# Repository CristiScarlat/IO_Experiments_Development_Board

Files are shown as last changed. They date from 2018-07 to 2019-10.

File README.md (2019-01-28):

IO_Experiments is a developer kit on a single board. The developer can connect any uC board including Arduino , Nucleo , RasperryPi to any of the devices on this board.

The board contains:
1. LCD 16x2 alphanumeric;
2. 8xleds driven by ULN2803;
3. 8xpush buttons;
4. 8xPots;
5. 7 segment display driven with cd4511;
6. 1x led matrix display driven by a MAX7219
7. 1xConnection made for Aurel 433MHz transiver;
8. 1xRTC PCF8563 I2C;
9. 3xIO Expanders MCP23017 I2C;
10. 1xEEPROM AT24CP I2C;
11. 1xFLASH MEM 25VF512A SPI ;
12. 1xDC Motor Drive L298;
13. 8xToggle Switches;
14. 1xRotary Encoder;
15. 1xJoystick;
16. 1xPiezzo Buzzer;
17. 1xLight Sensor;
18. 1xTemperature Sensor TMP36;
19 1xIR sensor 38KHz TSOP3483;
10. 1xDAC 12bit MCP4921 SPI ;
11. 1xADC 12bit MCP3201 SPI;
12. 8xRelays driven by ULN2803;

The boards has a 5V 3A power regulator and 3.3V 800mA power regulator.

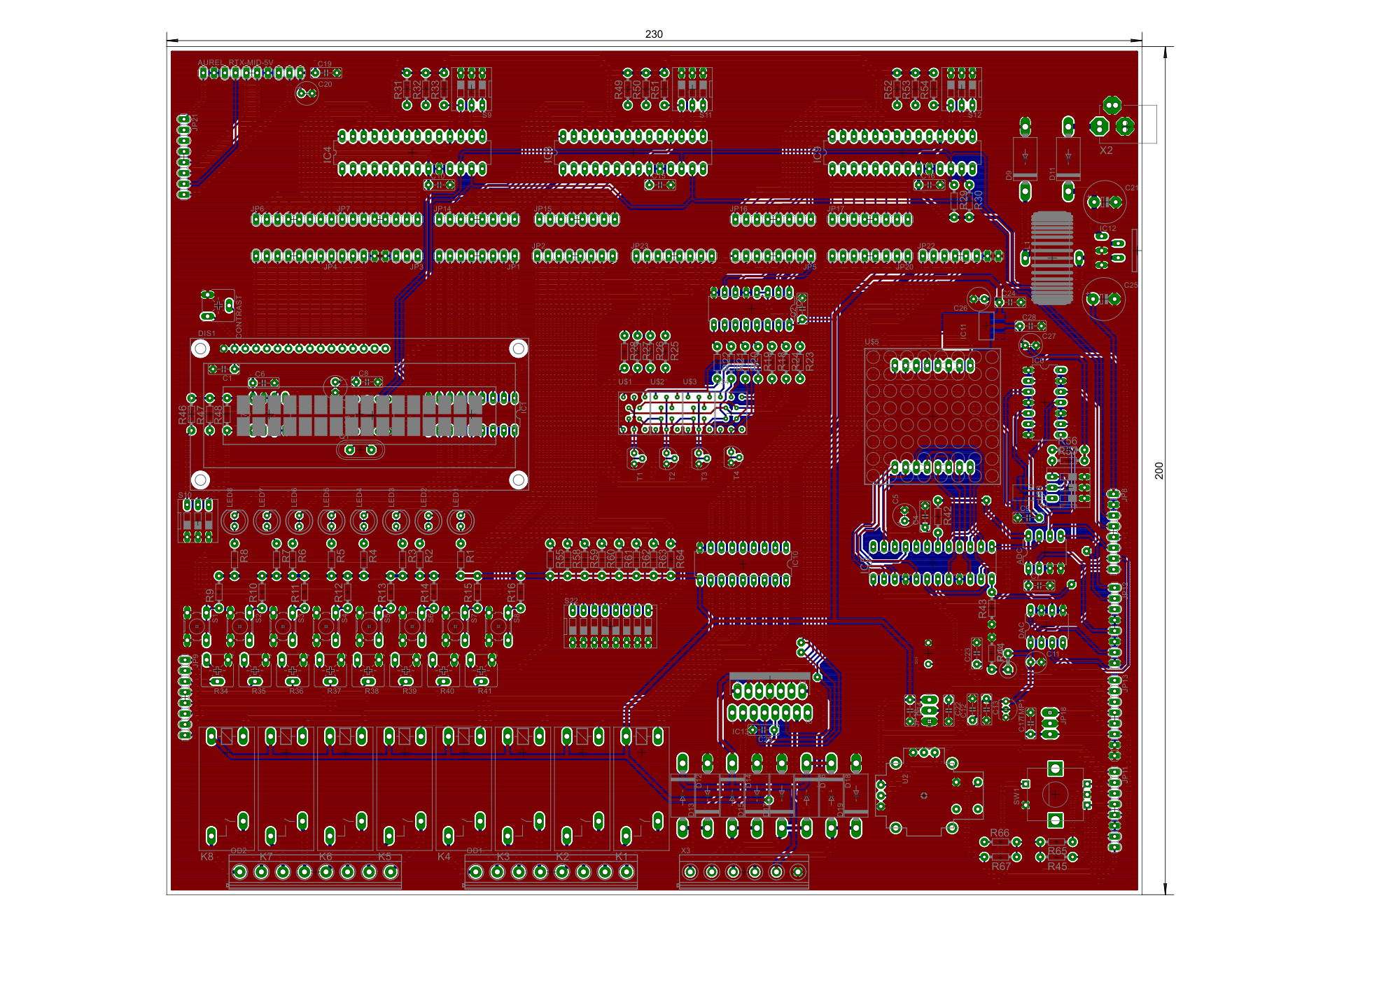
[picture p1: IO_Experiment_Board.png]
IO_EXPERIMENT_BOARD


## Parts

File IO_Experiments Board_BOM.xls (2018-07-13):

Qty | Value | Device | Package | Parts | DENUMIRE TME | PRET TME
1 |  | 0550_PKM13EPYH4002-B0 | BUZZER-12MM-NS-P5MM | SG1 | LD-BZEN-1201? | 1.2043RON/3buc
1 |  | LM2596TV | TO220-51 | IC12 | LM2596T-5.0? | 13.5RON/buc
1 |  | M03LONGPADS | 1X03_LONGPADS | IR | TSOP34838 | 2.08RON/buc
1 |  | R-US_0411/3V | 0411V | R17 | GM5516? | 0.2318RON/10buc
8 | 10-XX | 10-XX | B3F-10XX | B1, B2, B3, B4, B5, B6, B7, B8 | TACT-67N-F? | 0.1713RON/10buc
19 | 100nF | C5/2.5 | C5B2.5 | C1, C2, C4, C6, C7, C8, C9, C10, C12, C13, C14, C15, C16, C17, C19, C23, C29,C24, C28 | CC-100N? | 0.04901RON/100buc
3 | 100uF | CPOL-EUE2.5-6 | E2,5-6 | C20, C26, C27 | KM100/16? | 0.12RON/25buc
38 | 10k | RRS1/8 | RS1/8 | R9, R10, R11, R12, R13, R14, R15, R16, R45, R55, R58, R59, R60, R61, R62, R63, R64, R65, R66, R67,R29, R30, R31, R32, R33, R43, R44, R46, R47, R48, R49, R50, R51, R52, R53, R54, R56, R57 | CF1/4W-10K? | 0.02662RON/100buc
2 | 1N5822 | 1N5822 | DO201-15 | D9, D11 | 1N5822? | 0.3932RON/10buc
3 | 1uF | CPOL-EUE2.5-6 | E2,5-6 | C3, C5,C11 | CM-1U | 0.21524RON/10buc
9 | 20k | TRIM_EU-CA6V | CA6V | CONTRAST, R34, R35, R36, R37, R38, R39, R40, R41 | CA6V-10K? | 0.5689RON/5buc
15 | 220 | RRS1/8 | RS1/8 | R1, R2, R3, R4, R5, R6, R7, R8, R18, R19, R20, R21, R22, R23, R24 | CF1/4WS-220R | 0.0291RON/100buc
1 | 25VF512A-33SAE | 25VF512A-33SAE | SOIC-8 | U$8 | 25VF512A-33SAE? | 2.4427RON/3buc
1 | 27k | REZISTORSRS1/8 | RS1/8 | R42 | CF1/4WS-27K? | 0.02905RON/100buc
1 | 32.768 kHz | CRYSTAL_THT | QS | Q1 | 32.768K-TC38 | 0.6109RON/5buc
5 | 3DIP_SW | DS03 | DS-03 | S9, S10, S11, S12, S13 | DS-03 | 2.5057RON/2buc
4 | 4.7k | RRS1/8 | RS1/8 | R25, R26, R27, R28 | MF0207FTE-4K7? | 0.07144RON/100buc
1 | 4511N | 4511N | DIL16 | IC2 | CD4511BE? | 1.1205RON/3buc
2 | 470uF | CPOL-EUE5-10.5 | E5-10,5 | C21, C25 | CE-470/16PHT? | 0.16463RON/25buc
1 | 74125N | 74125N | DIL14 | IC6 | SN74AHC125N? | 0.7279RON/5buc
1 | 8DIP_SW | DS08 | DS-08 | S22 | DS-08? | 4.4522RON/buc
1 | AT24CP | AT24CP | DIL08 | IC7 | AT24C02C-PUM? | 1.45RON/3buc
4 | BC547 | BC547 | TO92 | T1, T2, T3, T4 | BC547A? | 0.08948RON/25buc
1 | EC12E_SW | EC12E_SW ENCODER | ALPS_EC12E_SW | SW1 | ED16112O? | 9.31RON/buc
1 | FH254-106DF08500V | FH254-106DF08500V_STD | 1X06 | EXT_SENS | ZL262-6SG? | 0.24RON/10buc
20 | FH254-108DF08500V | FH254-108DF08500V | 1X08 | 7SEG, BUTTONS, COMMUNICATION, DIP_SW, ENCJOY, JP6, JP7, JP12, JP14, JP15, JP16, JP17, JP20, JP21, JP22, LCDH, LCDL, LEDS, POTS, SENSORS | ZL262-8SG? | 0.28426RON/10buc
1 | FH254-110DF08500V | FH254-110DF08500V | 1X10 | AUREL_RTX-MID-5V | ZL262-10SG? | 0.26649RON/10buc
1 | LFD039AUE-102A? | LFD039AUE-102A? | LFD039AUE-102A? | 1 | LFD039AUE-102A? | 3.04RON/buc
8 | G2RA | G2RA | G2RA | K1, K2, K3, K4, K5, K6, K7, K8 | G2R-1A4-5DC? | 5.55RON/buc
8 | GREEN_5mm | L-7113GT | LED5MM | LED1, LED2, LED3, LED4, LED5, LED6, LED7, LED8 | OSNR5134B? | 0.1283RON/20buc
1 | JOYSTICK | JOYSTICKPTH | JOYSTICK | U2 | http://www.robofun.ro/joystick?search=joystick
1 | L298 | L298 | MULTIWATT-15 | IC13 | L298N? | 10.95RON/nuc
1 | LMD12088AUE-101A | LMD12088AUE-101A | NFM-12881BG-11 | U$5 | LMD12088AUE-101A | 6.69RON/buc
1 | MAX7219CNG | MAX7219CNG | DIL24-3 | IC5 | MAX7219CNG+ | 26.92RON/buc
8 | MBRA140 | 1N5400 | DO201-15 | D12, D13, D14, D15, D16, D17, D18, D19 | 1N5402? | 0.28922RON/10buc
3 | MCP23017SP | MCP23017SP | DIL28-3 | IC4, IC8, IC9 | MCP23017-E/SP? | 5.12RON/buc
1 | MCP3201-CI/P | MCP3201-CI/P | DIL08 | ADC | MCP3201-CI/P? | 10.74RON/buc
1 | MCP4921 | MCP4921 | DIL08 | DAC | MCP4921-E/P? | 8.10RON/buc
1 | MKDSN1,5/6-5,08 | MKDSN1,5/6-5,08 | MKDSN1,5/6-5,08 | X3
2 | MKDSN1,5/8-5,08 | MKDSN1,5/8-5,08 | MKDSN1,5/8-5,08 | OD1, OD2
1 | NX1117CE33Z | NX1117CE33Z,115 | SOT223 | IC11 | LD1117AS33? | 0.7942RON/3buc
1 | PCF8563P | PCF8563P | DIL08 | IC3
1 | POWERSUPPLY_DC21MMX | POWERSUPPLY_DC21MMX | POWERSUPPLY_DC-21MM | X2 | PC-GK1.3 | 0.5784RON/5buc
1 | SFT1030 | SFT1030 | SFT1030 | L1 | DTPU033A1? | 3.10RON/buc
1 | TMP36 | TMP36 | BC-TO92 | TMP1 | TMP36GT9Z? | 4.30RON/buc
1 | LCD_16X2 | LCD_16X2 | LCD_16X2 | DIS1 | RC1602B? | 23.22RON.buc
2 | ULN2803 | ULN2803A | DIL18 | IC1, IC10 | ULN2803A? | 2.1743RON/buc

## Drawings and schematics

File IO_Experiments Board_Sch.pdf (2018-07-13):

# LED_MATRIX

433MHz UART RX_TX | SURSA TENSIUNE

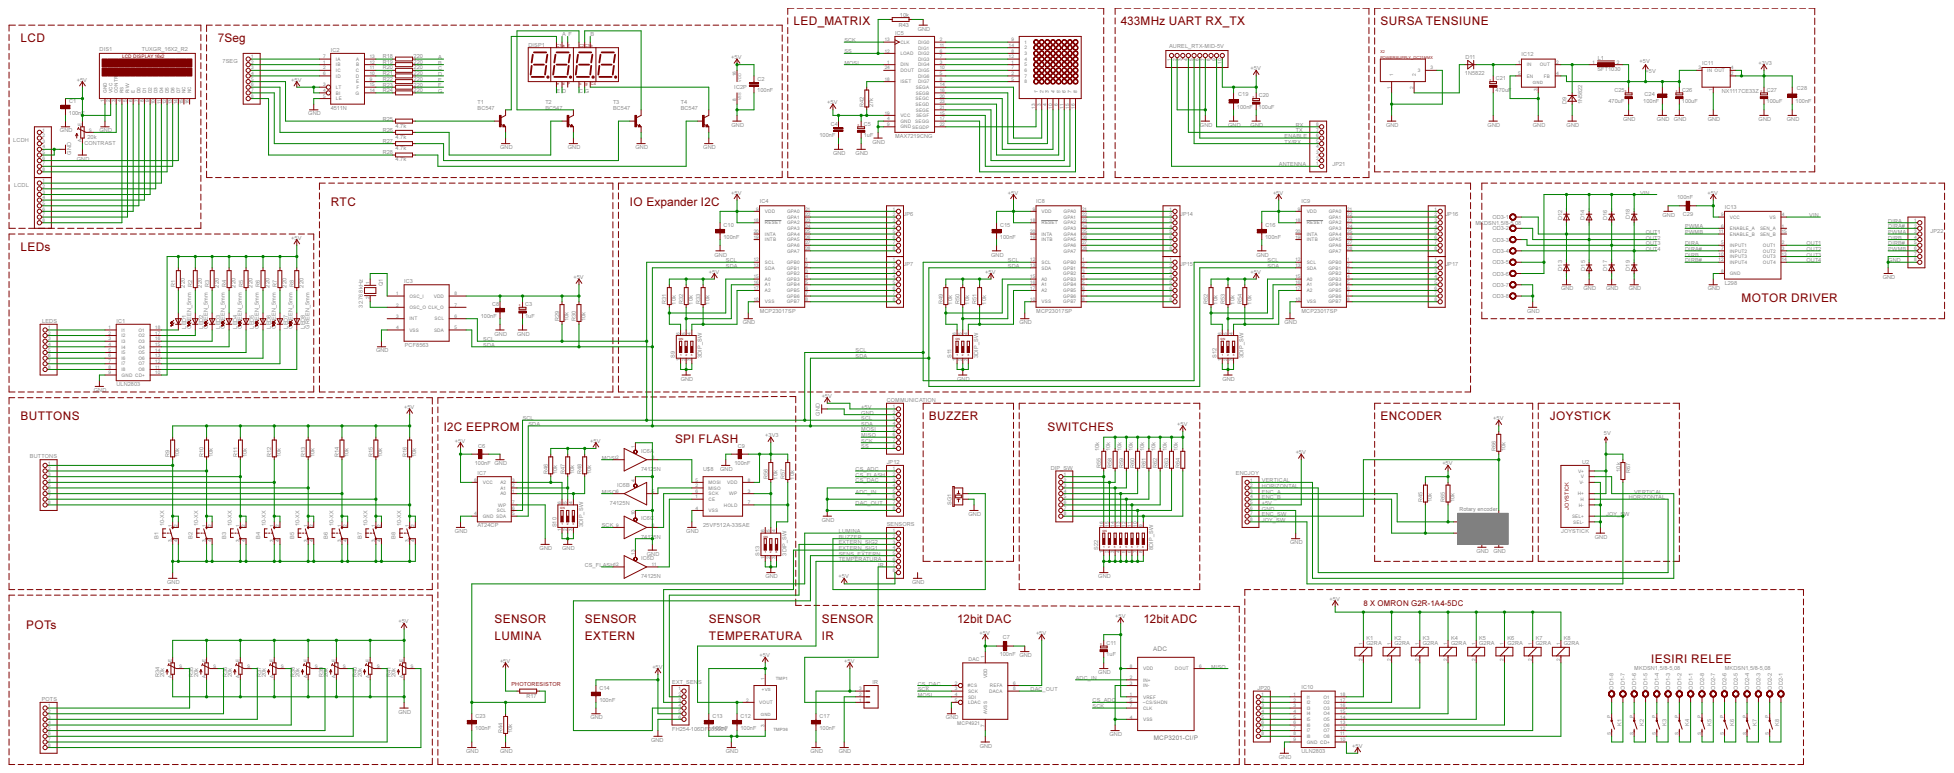
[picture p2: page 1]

SpiceOrder 1 SpiceOrder 2

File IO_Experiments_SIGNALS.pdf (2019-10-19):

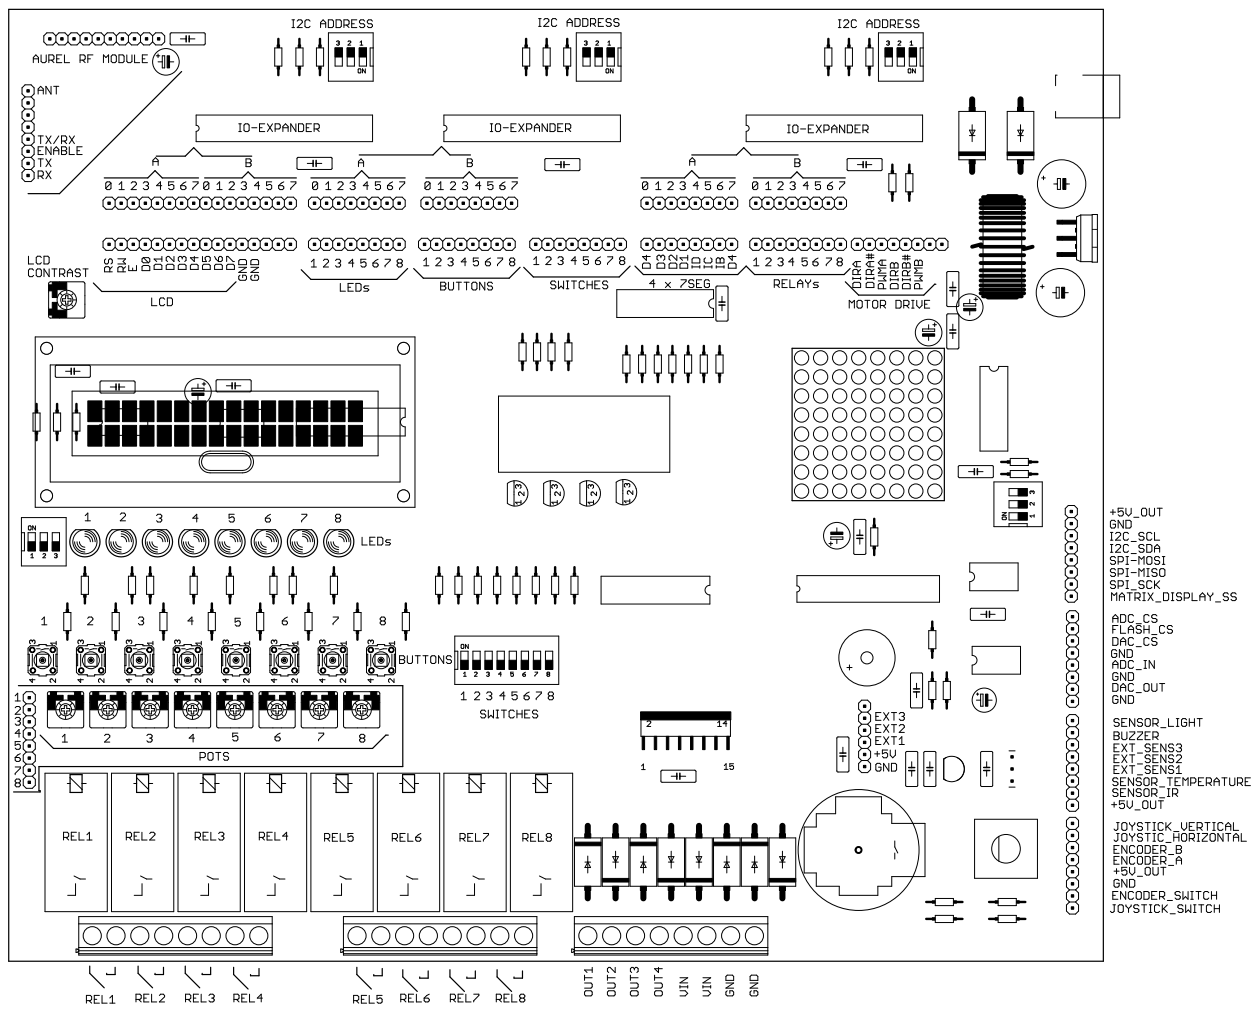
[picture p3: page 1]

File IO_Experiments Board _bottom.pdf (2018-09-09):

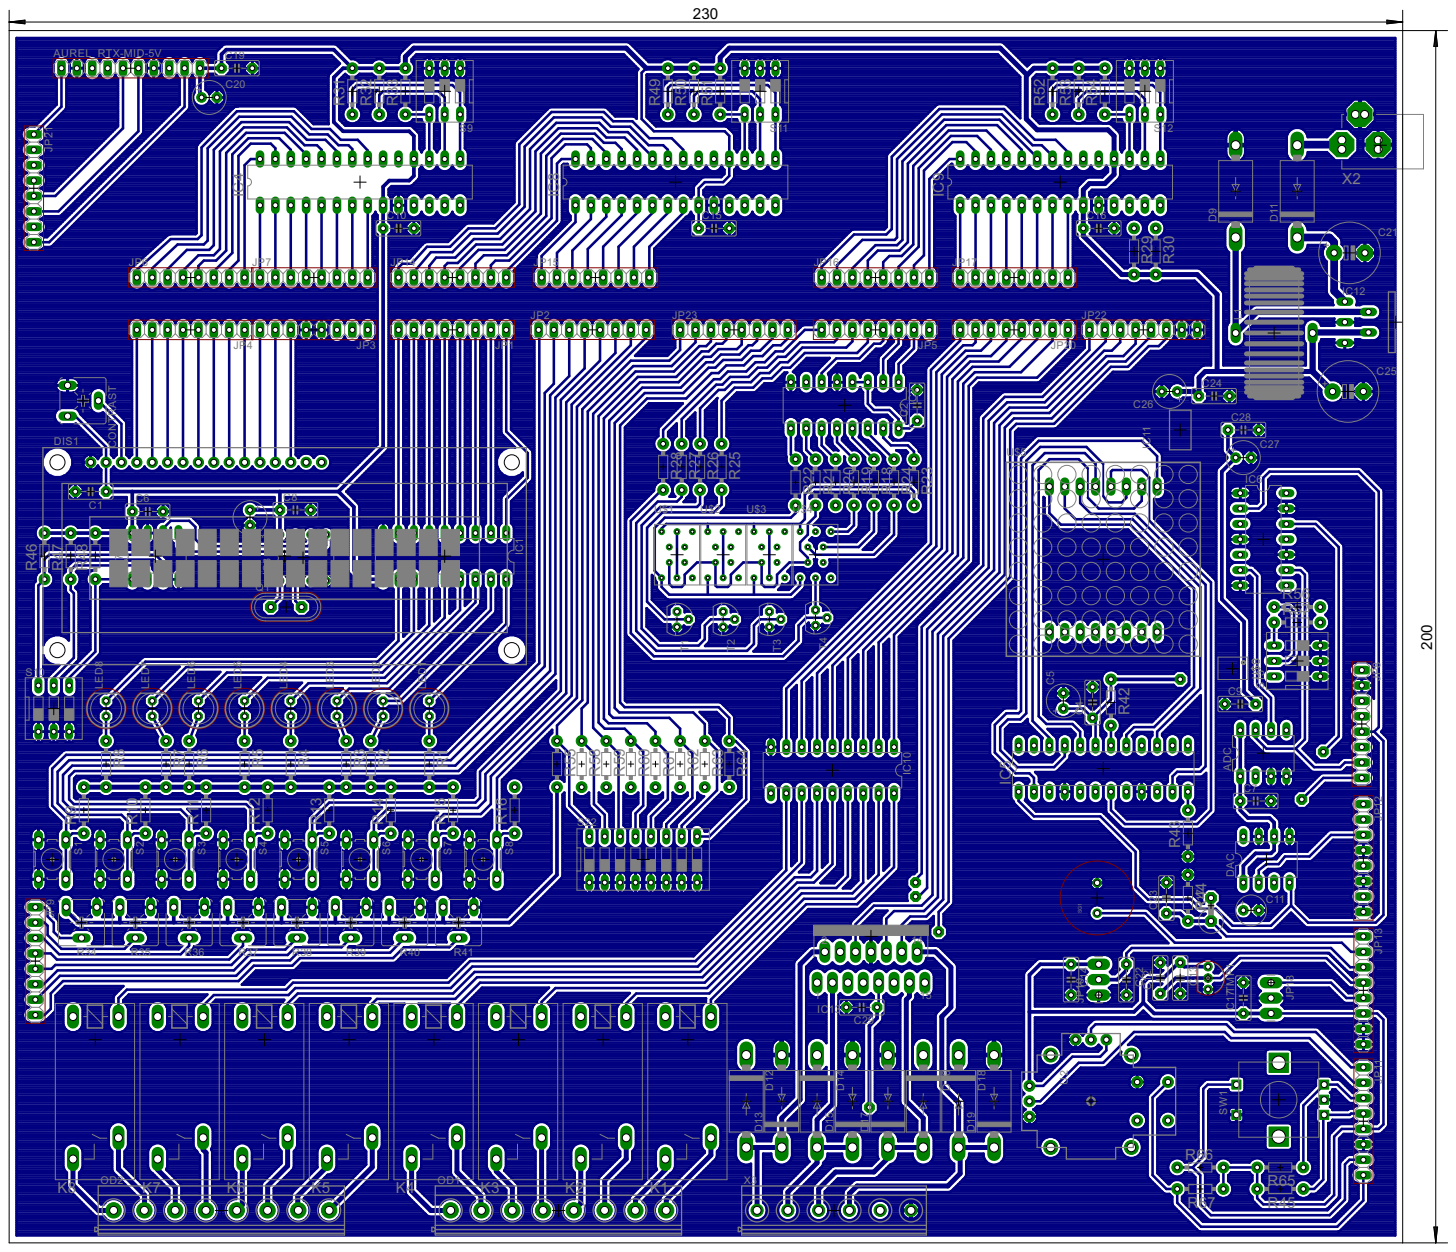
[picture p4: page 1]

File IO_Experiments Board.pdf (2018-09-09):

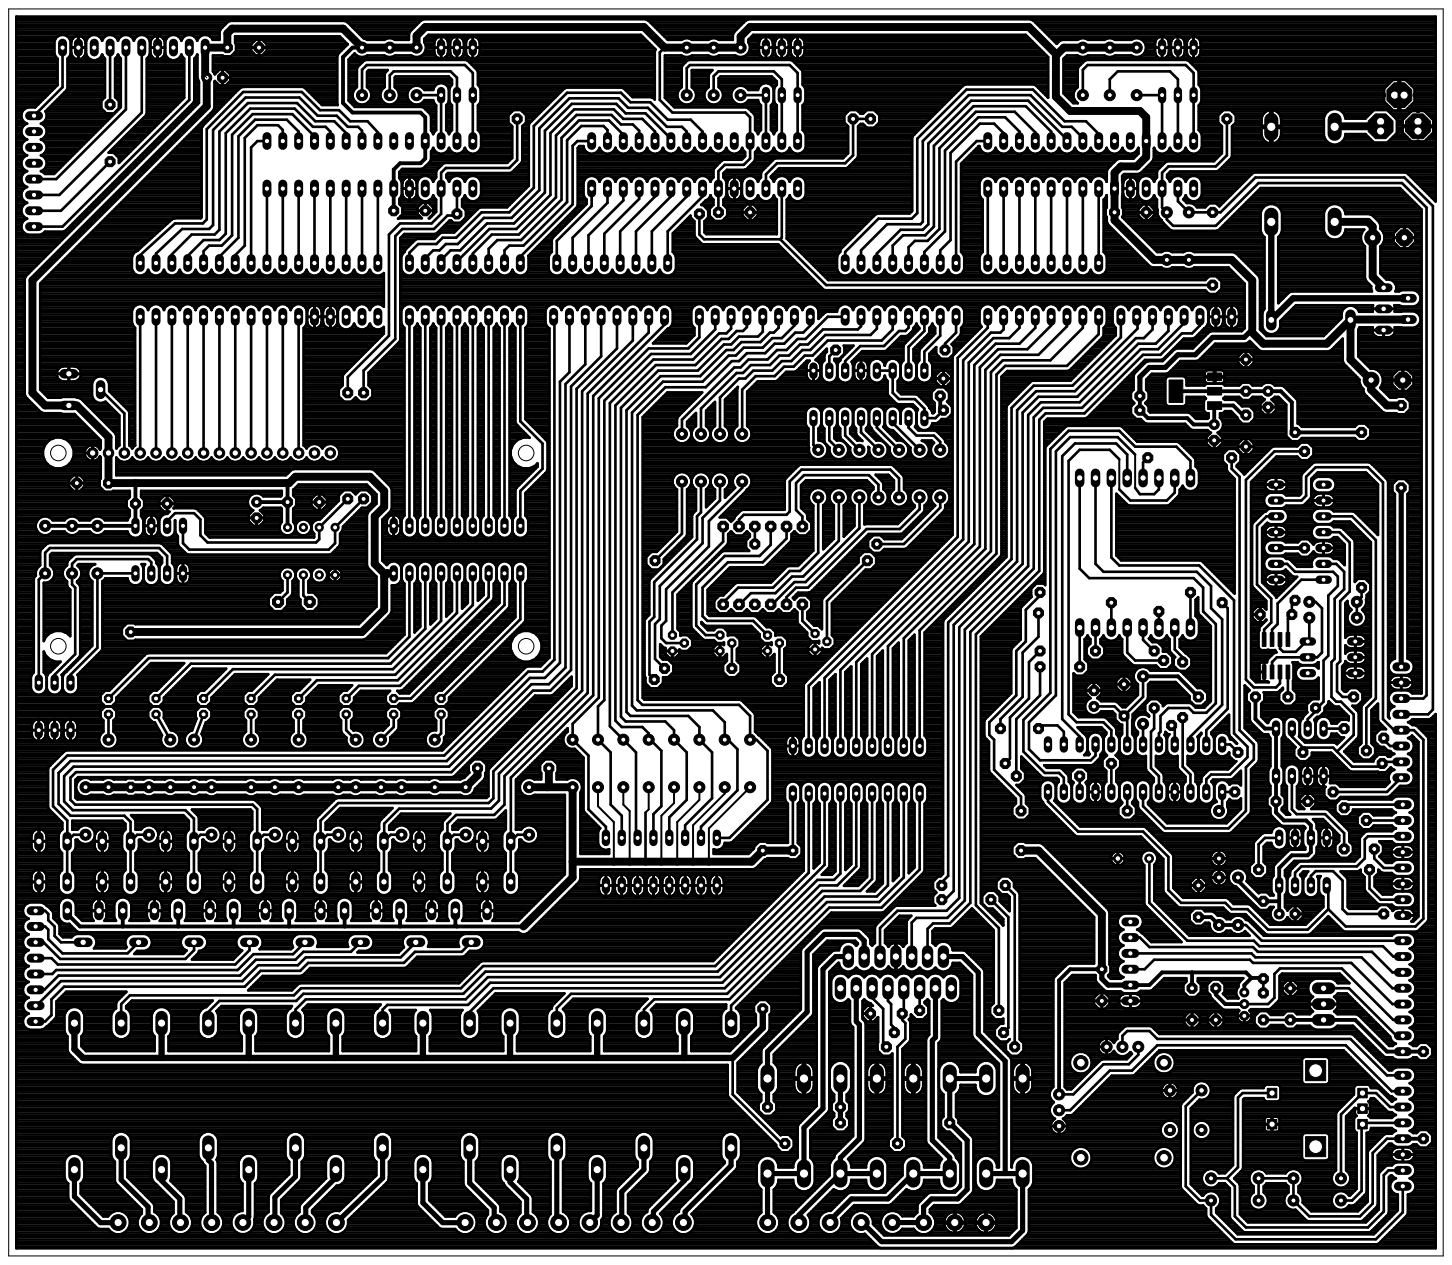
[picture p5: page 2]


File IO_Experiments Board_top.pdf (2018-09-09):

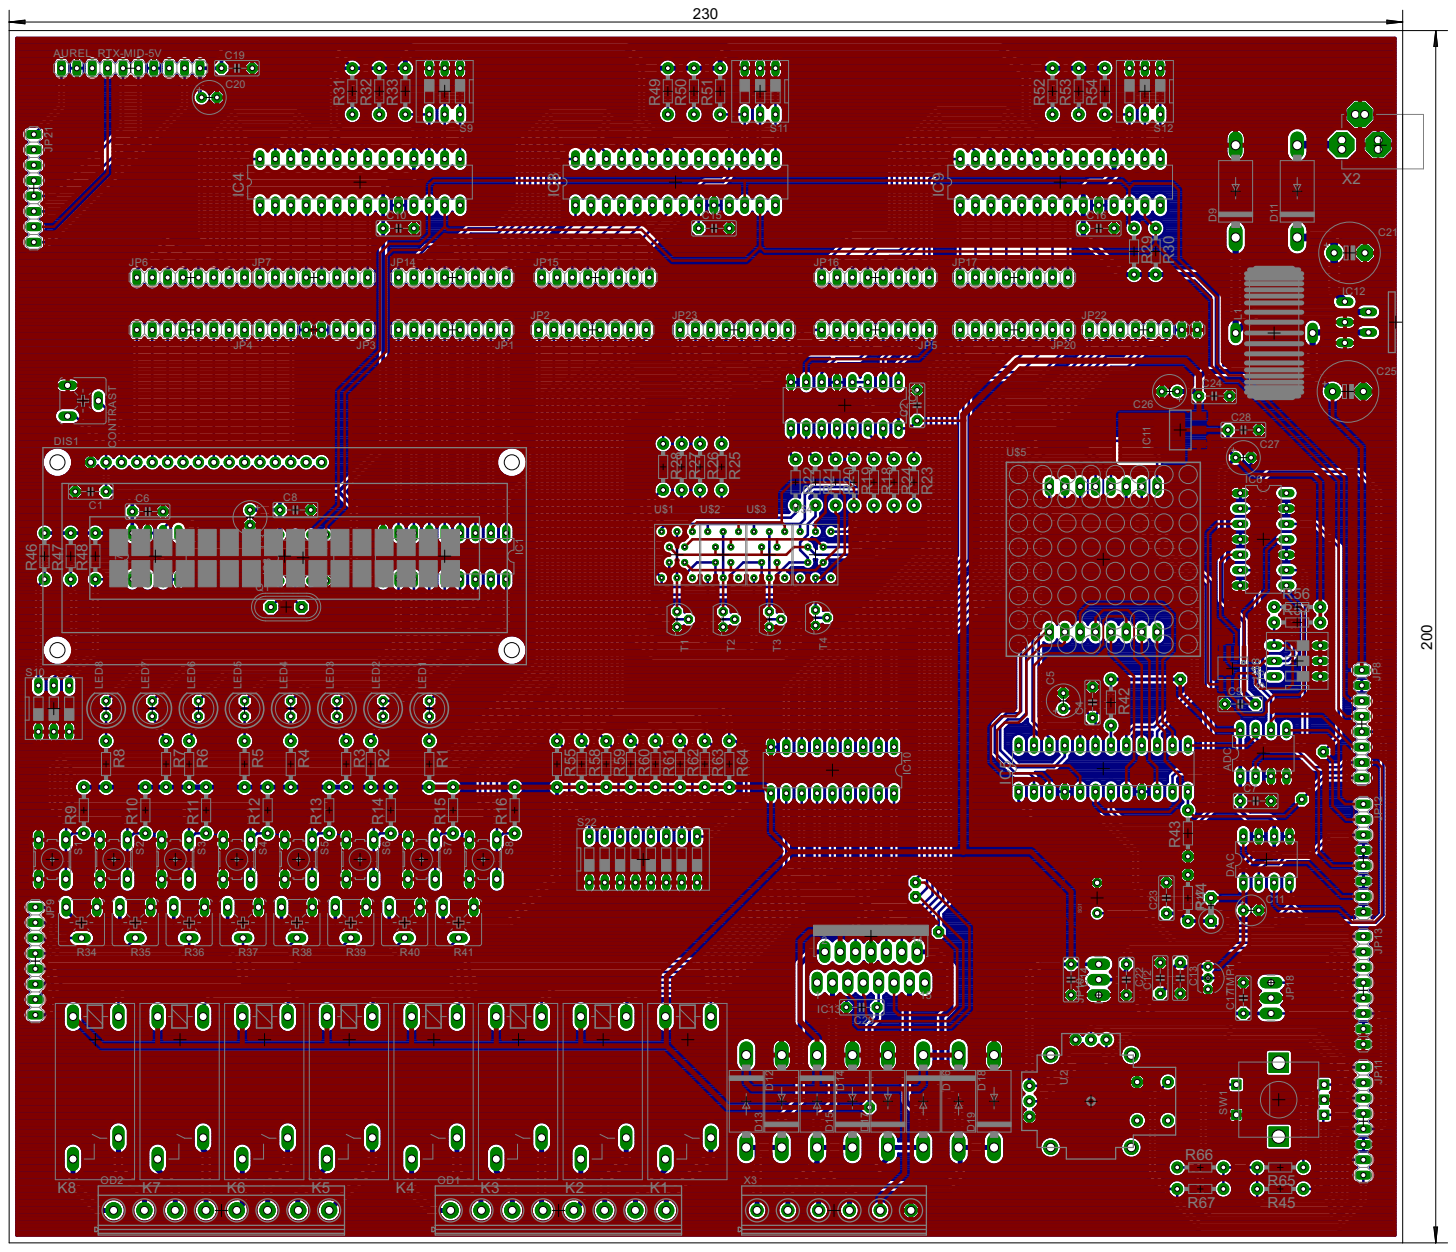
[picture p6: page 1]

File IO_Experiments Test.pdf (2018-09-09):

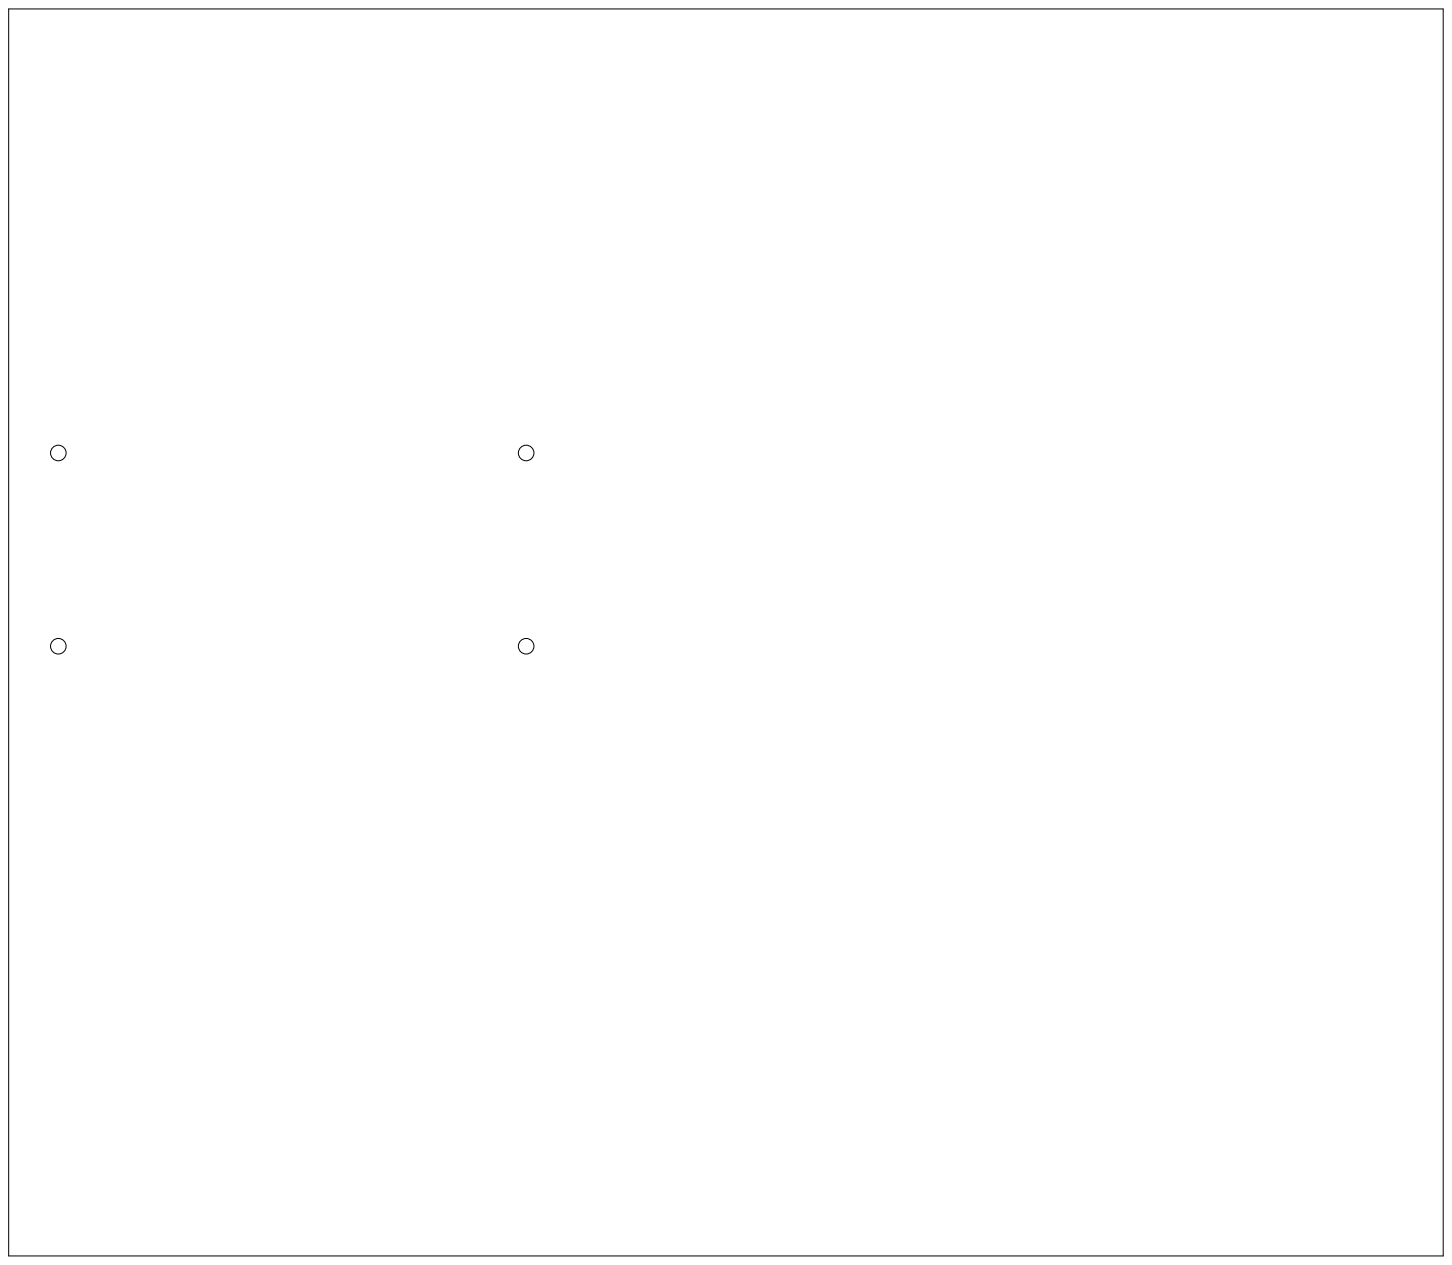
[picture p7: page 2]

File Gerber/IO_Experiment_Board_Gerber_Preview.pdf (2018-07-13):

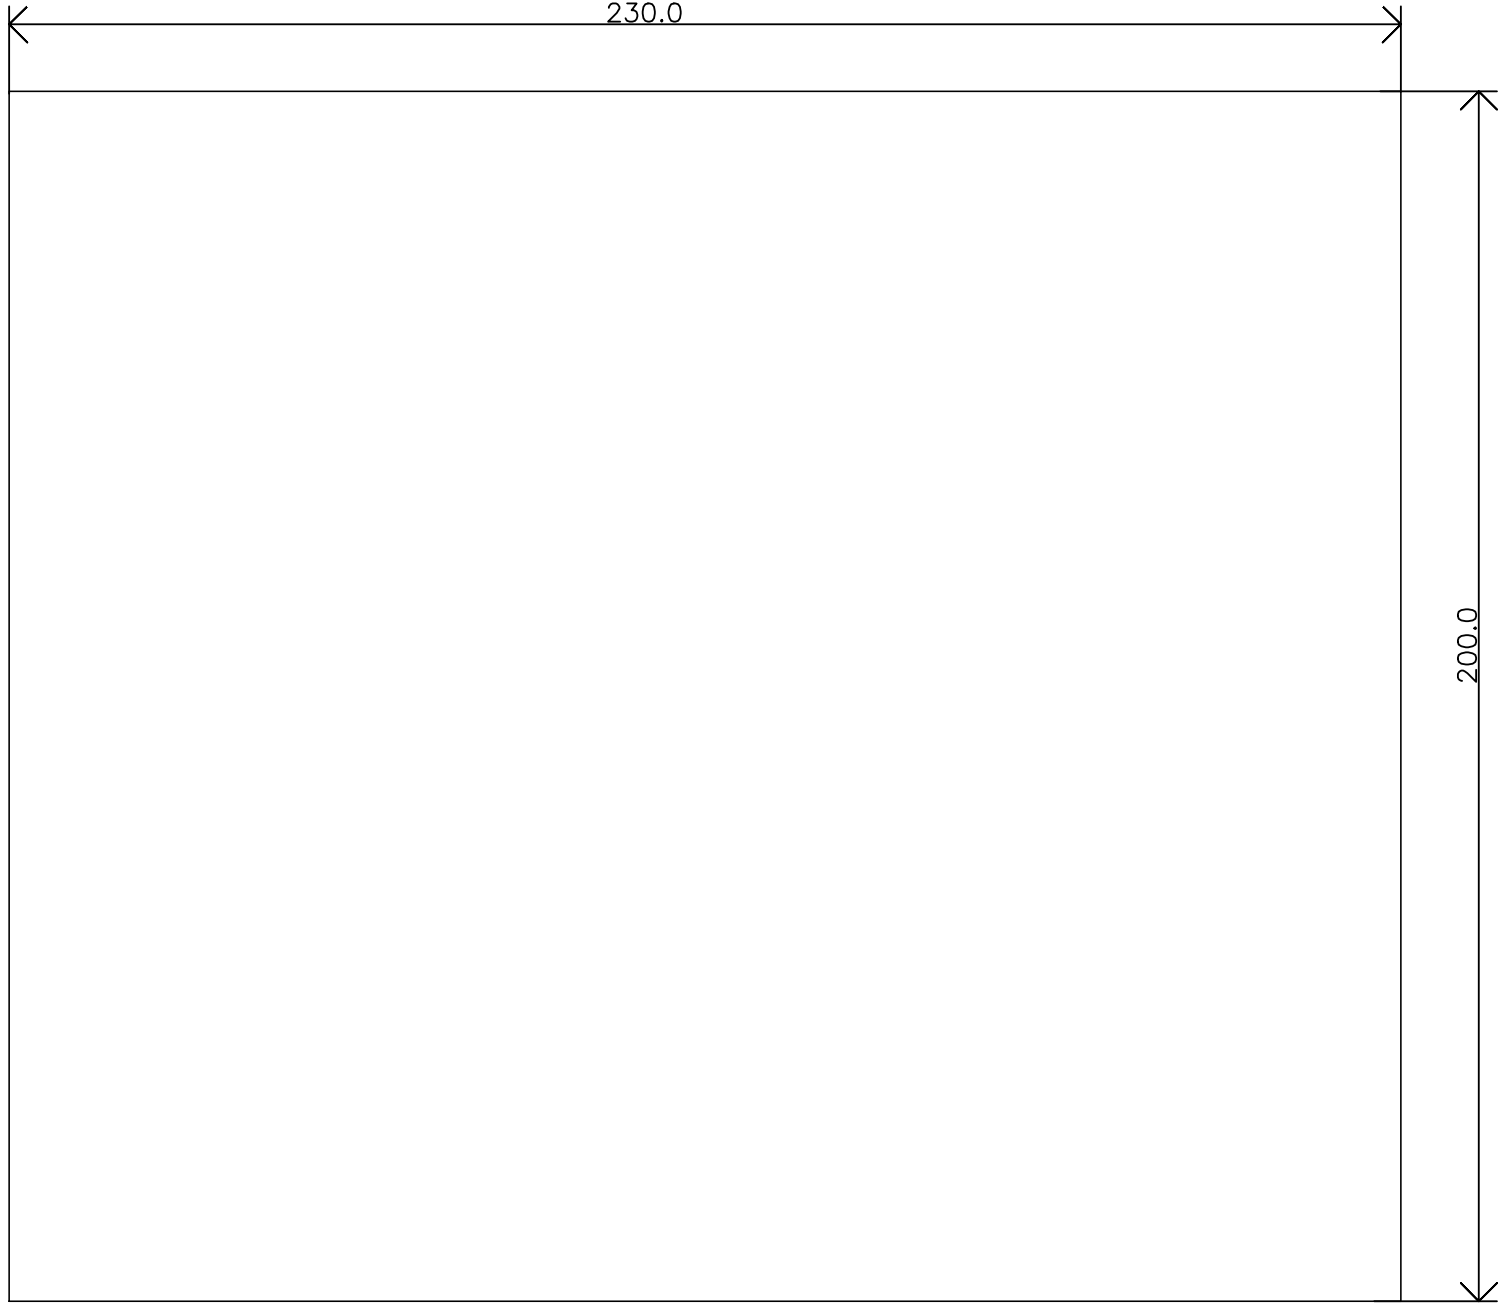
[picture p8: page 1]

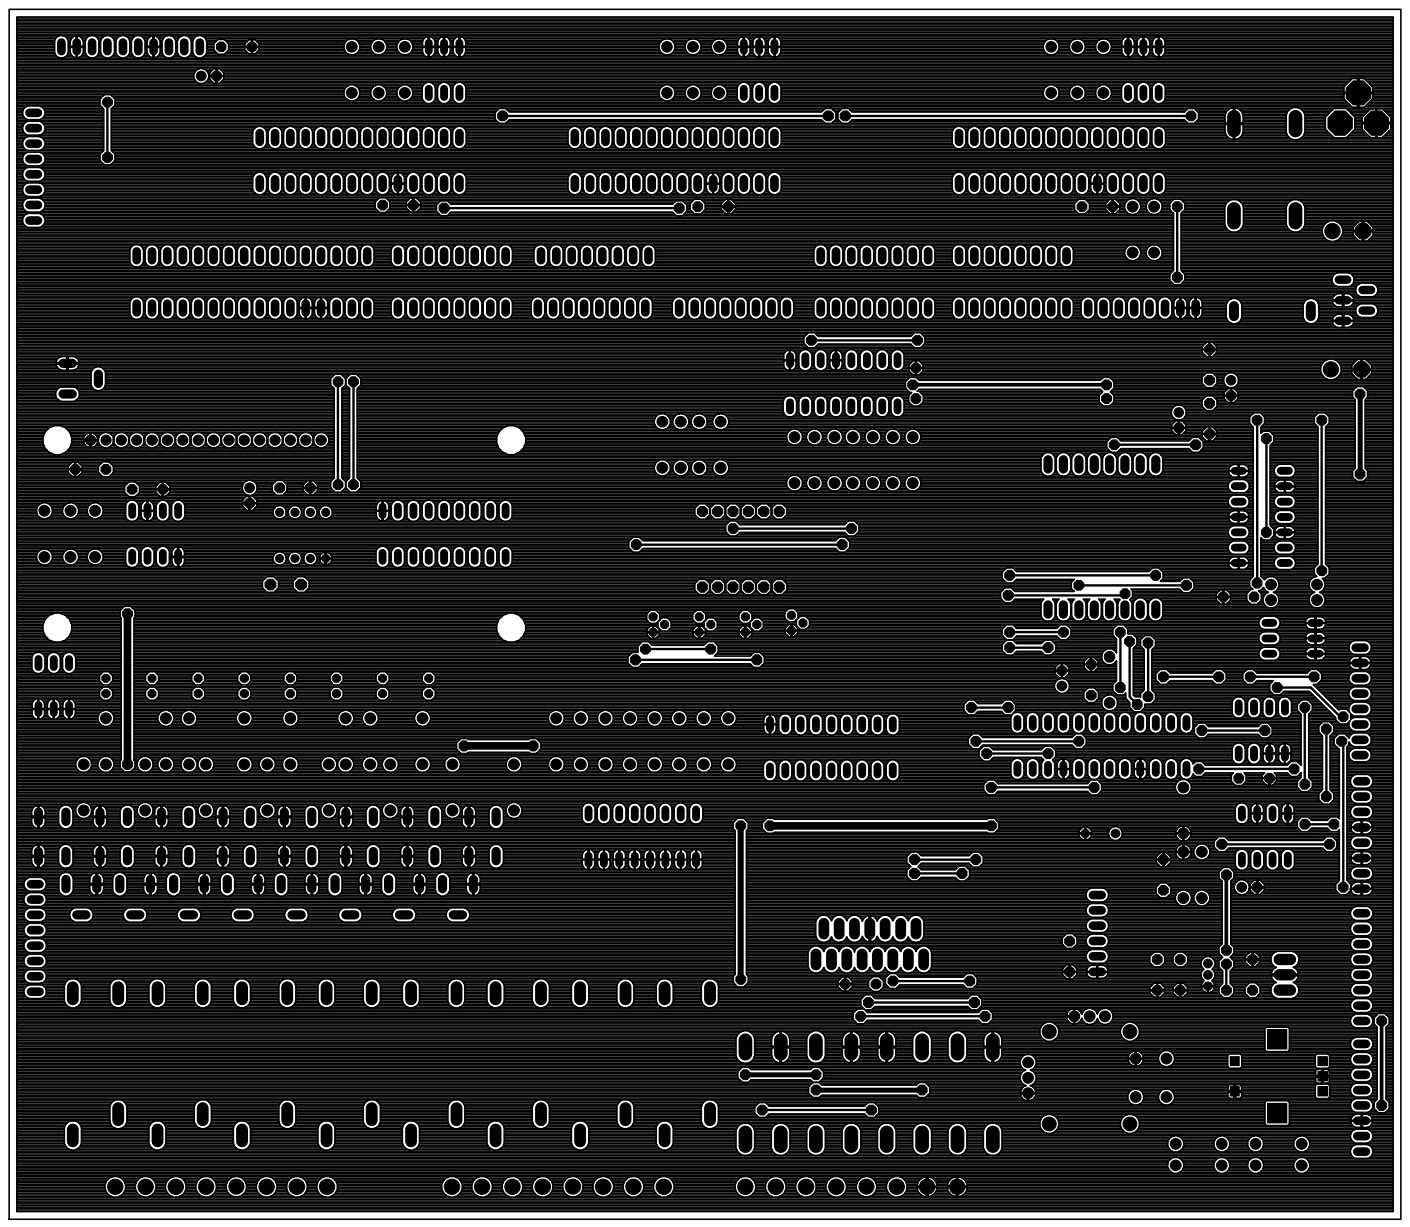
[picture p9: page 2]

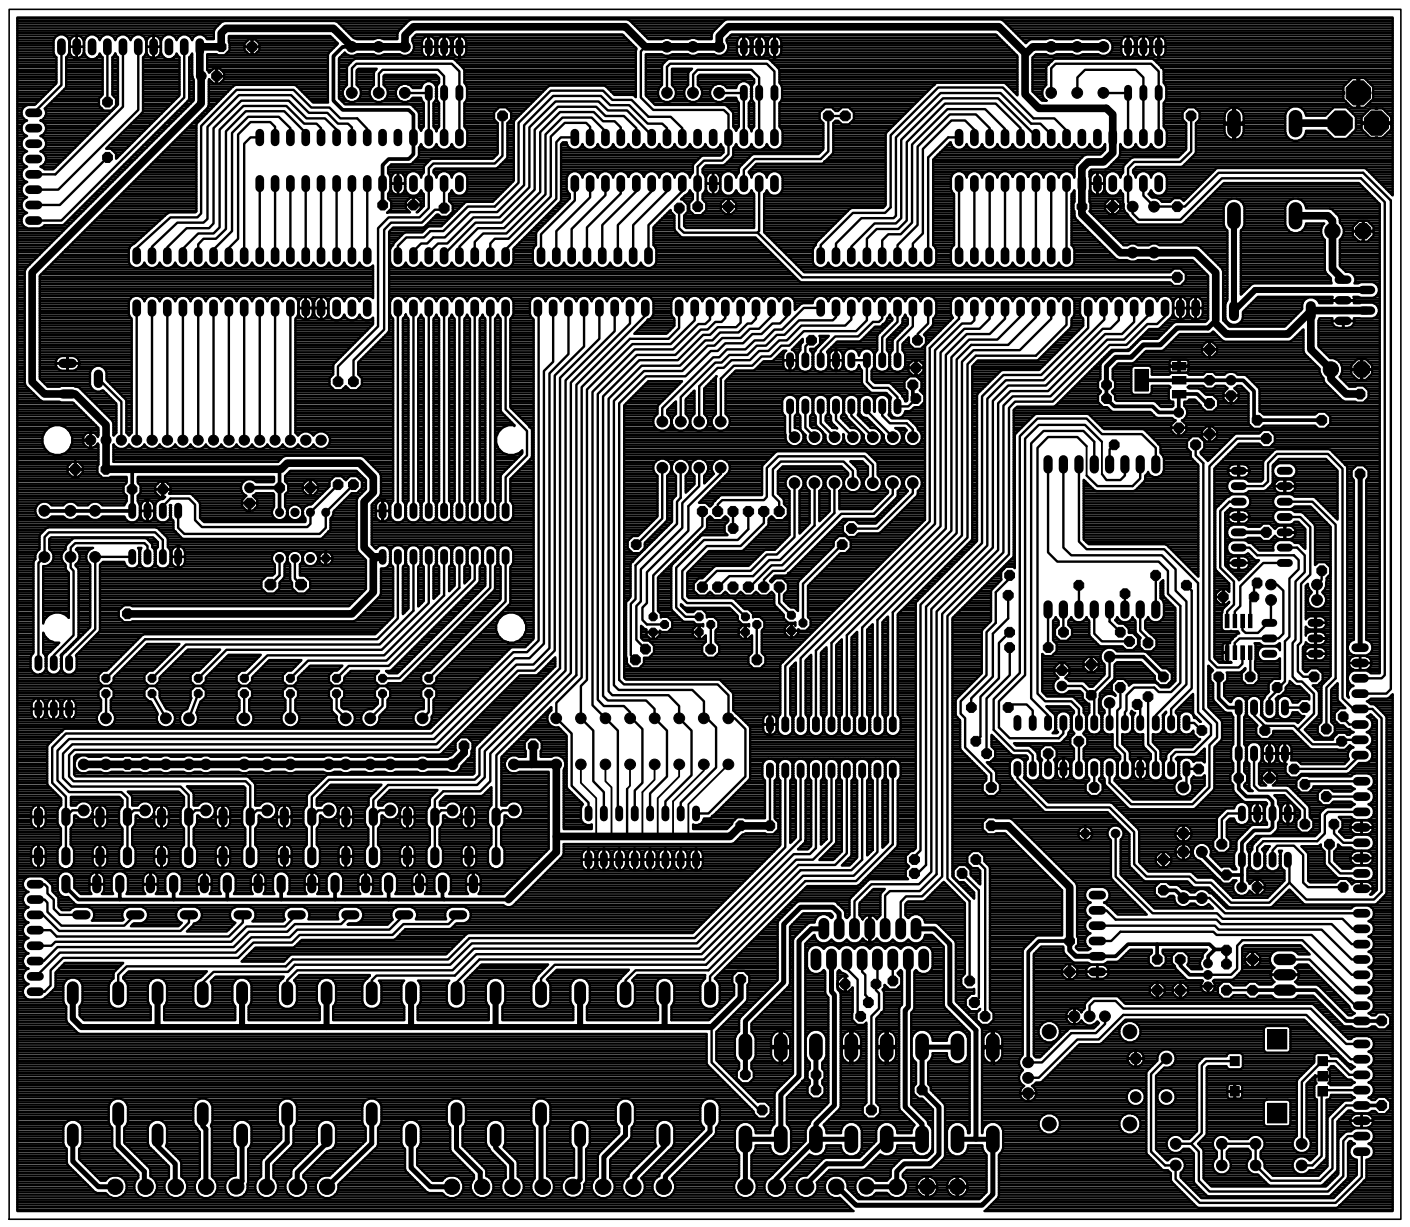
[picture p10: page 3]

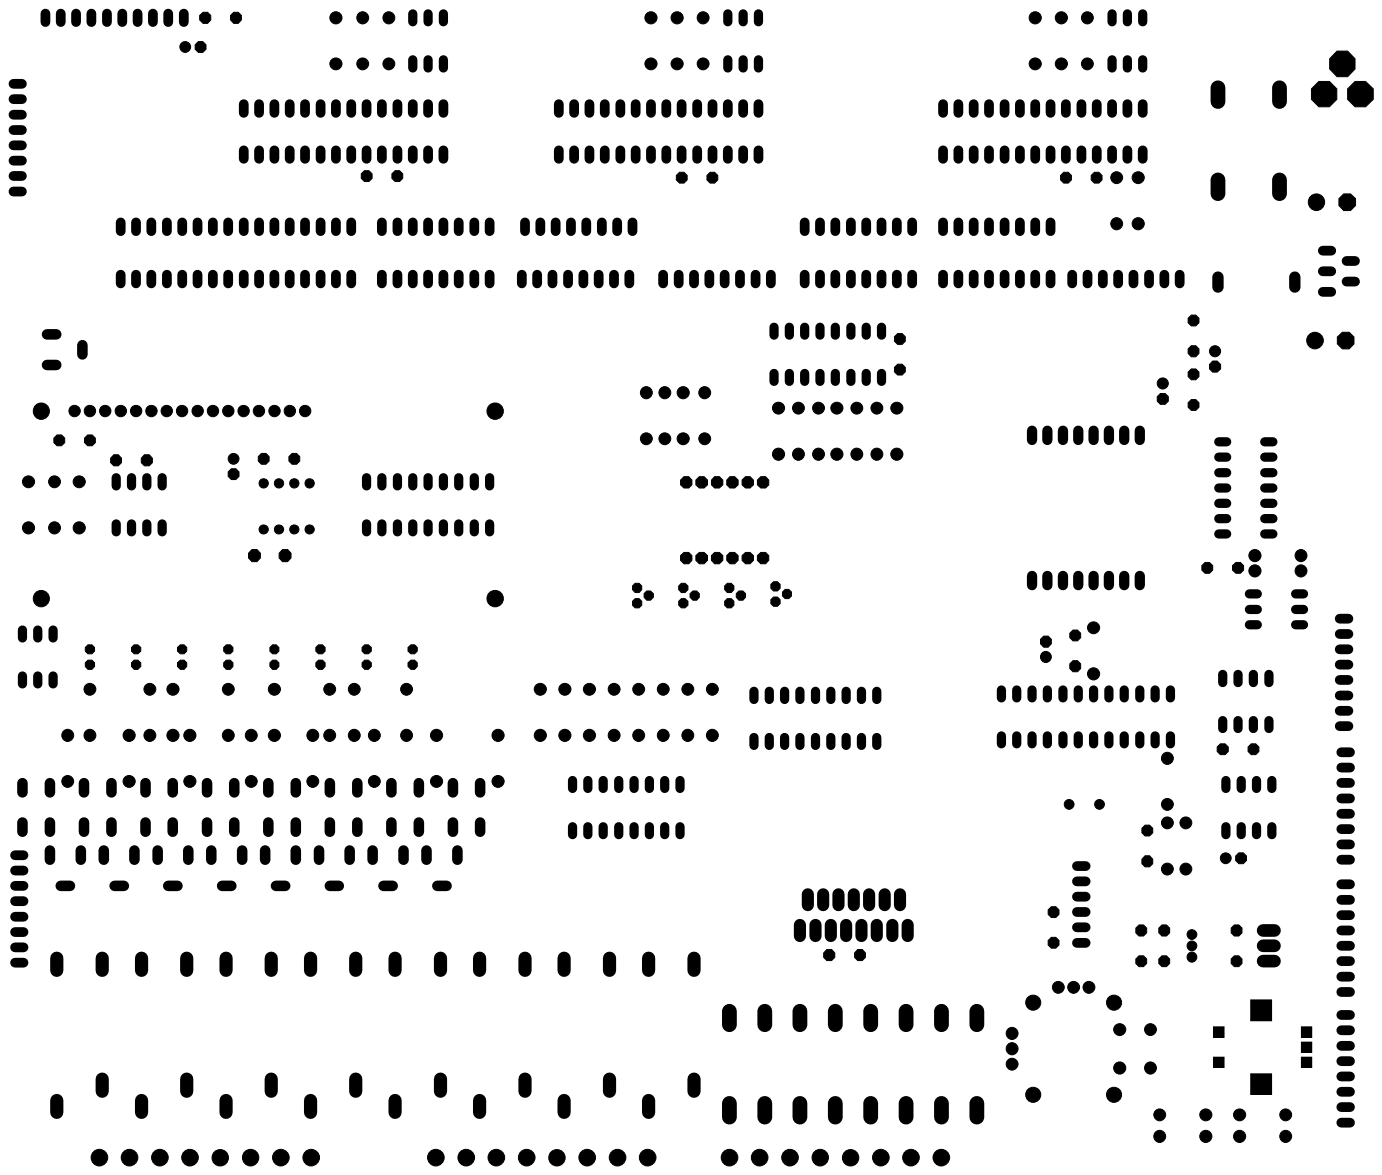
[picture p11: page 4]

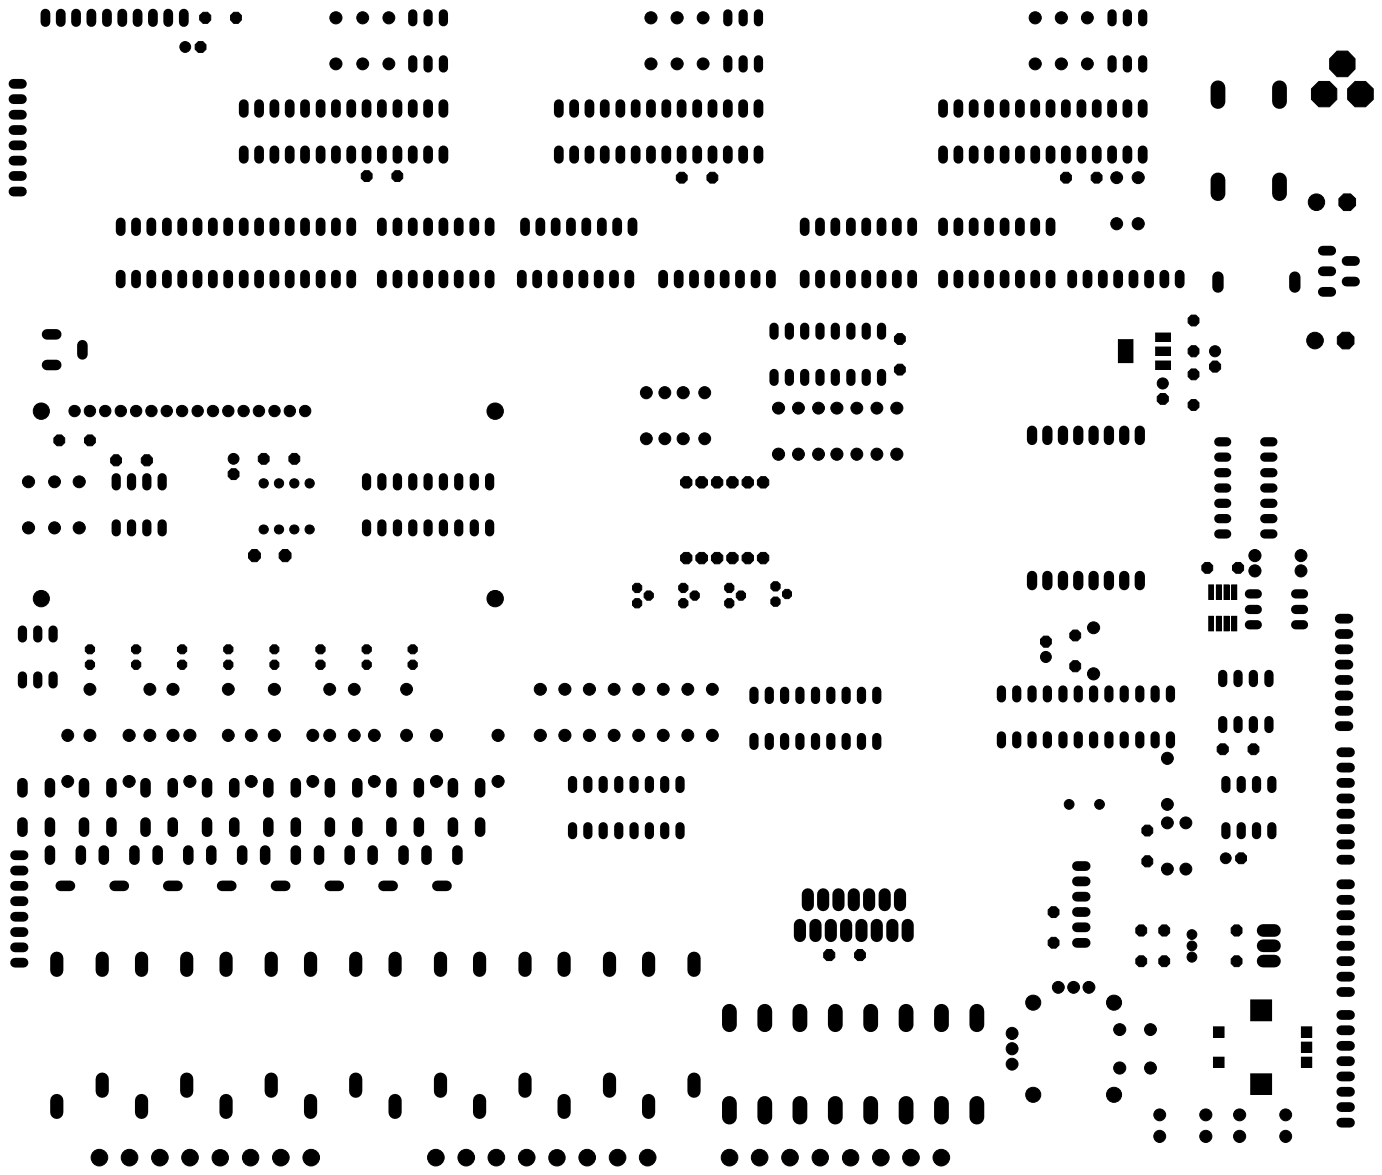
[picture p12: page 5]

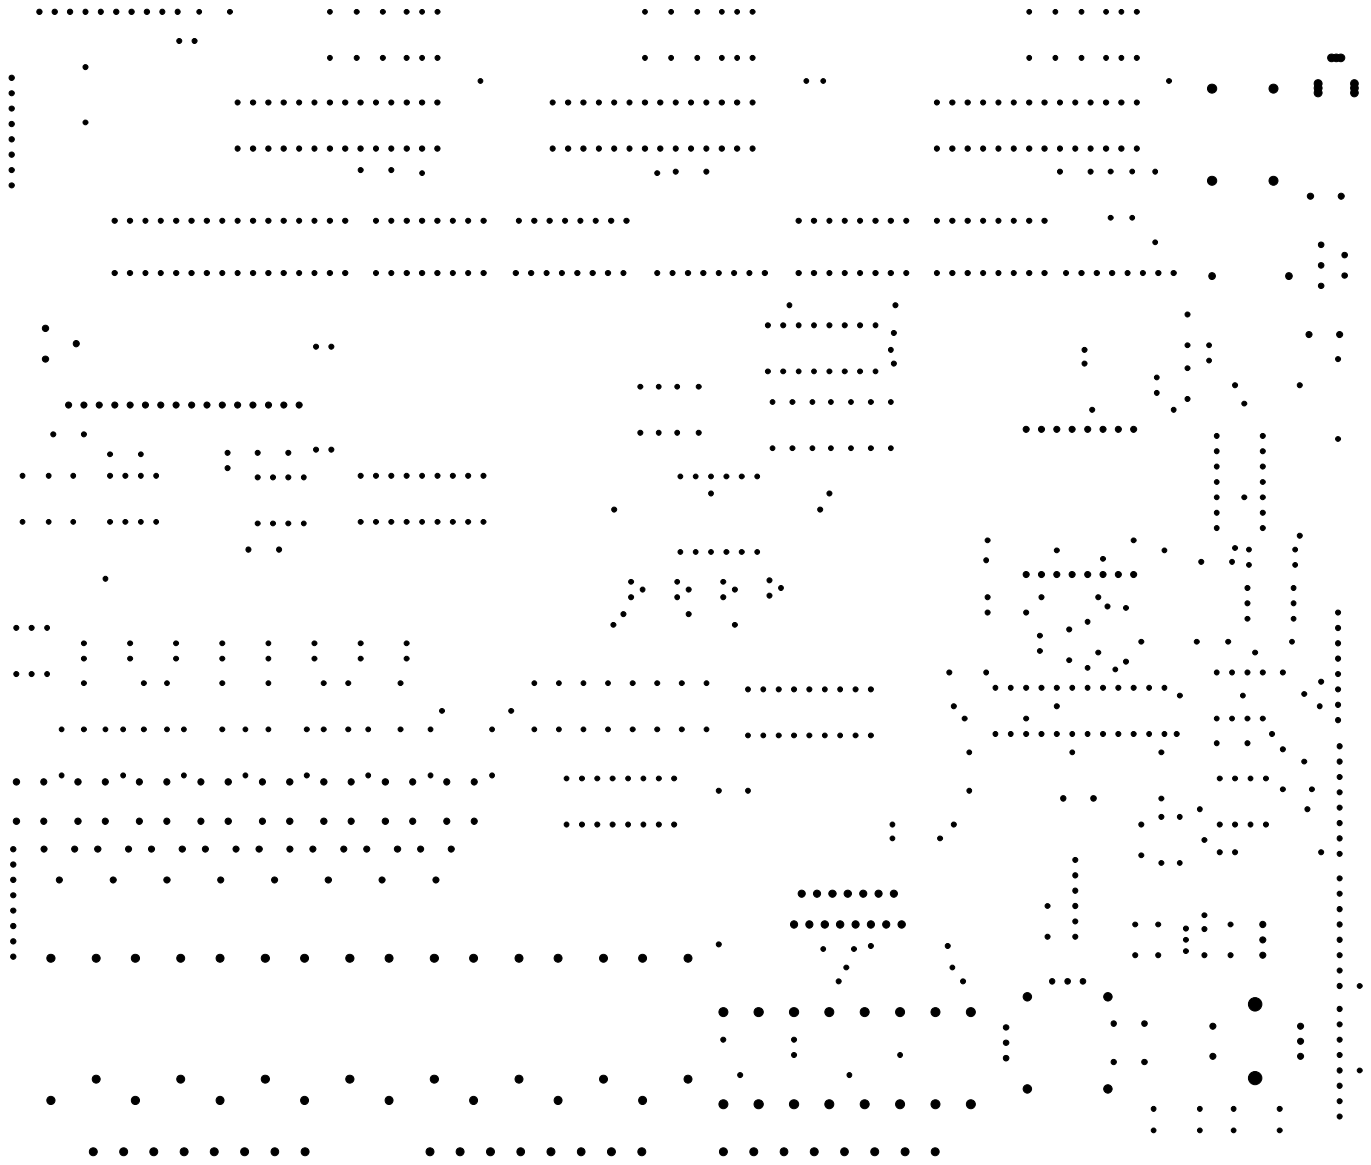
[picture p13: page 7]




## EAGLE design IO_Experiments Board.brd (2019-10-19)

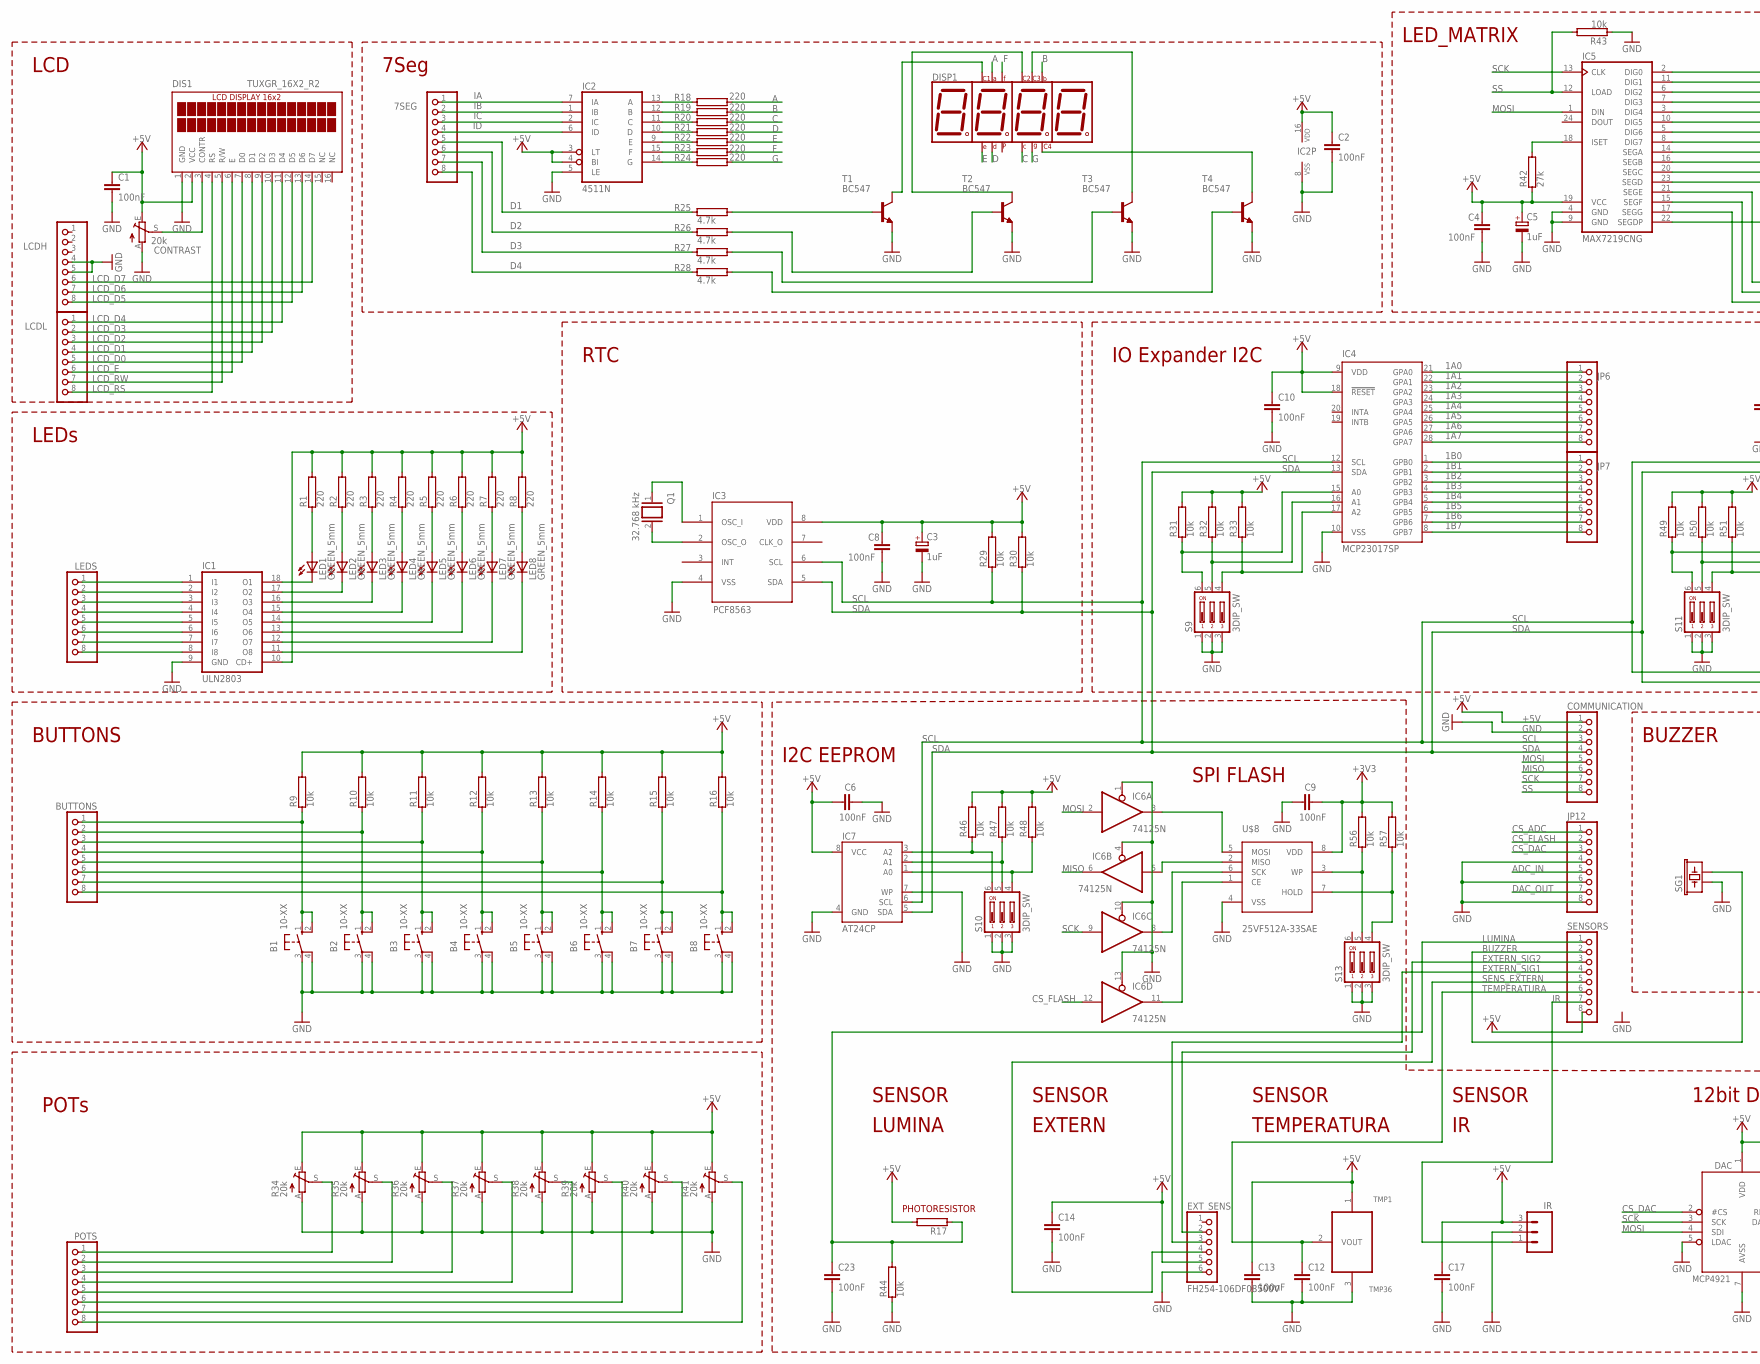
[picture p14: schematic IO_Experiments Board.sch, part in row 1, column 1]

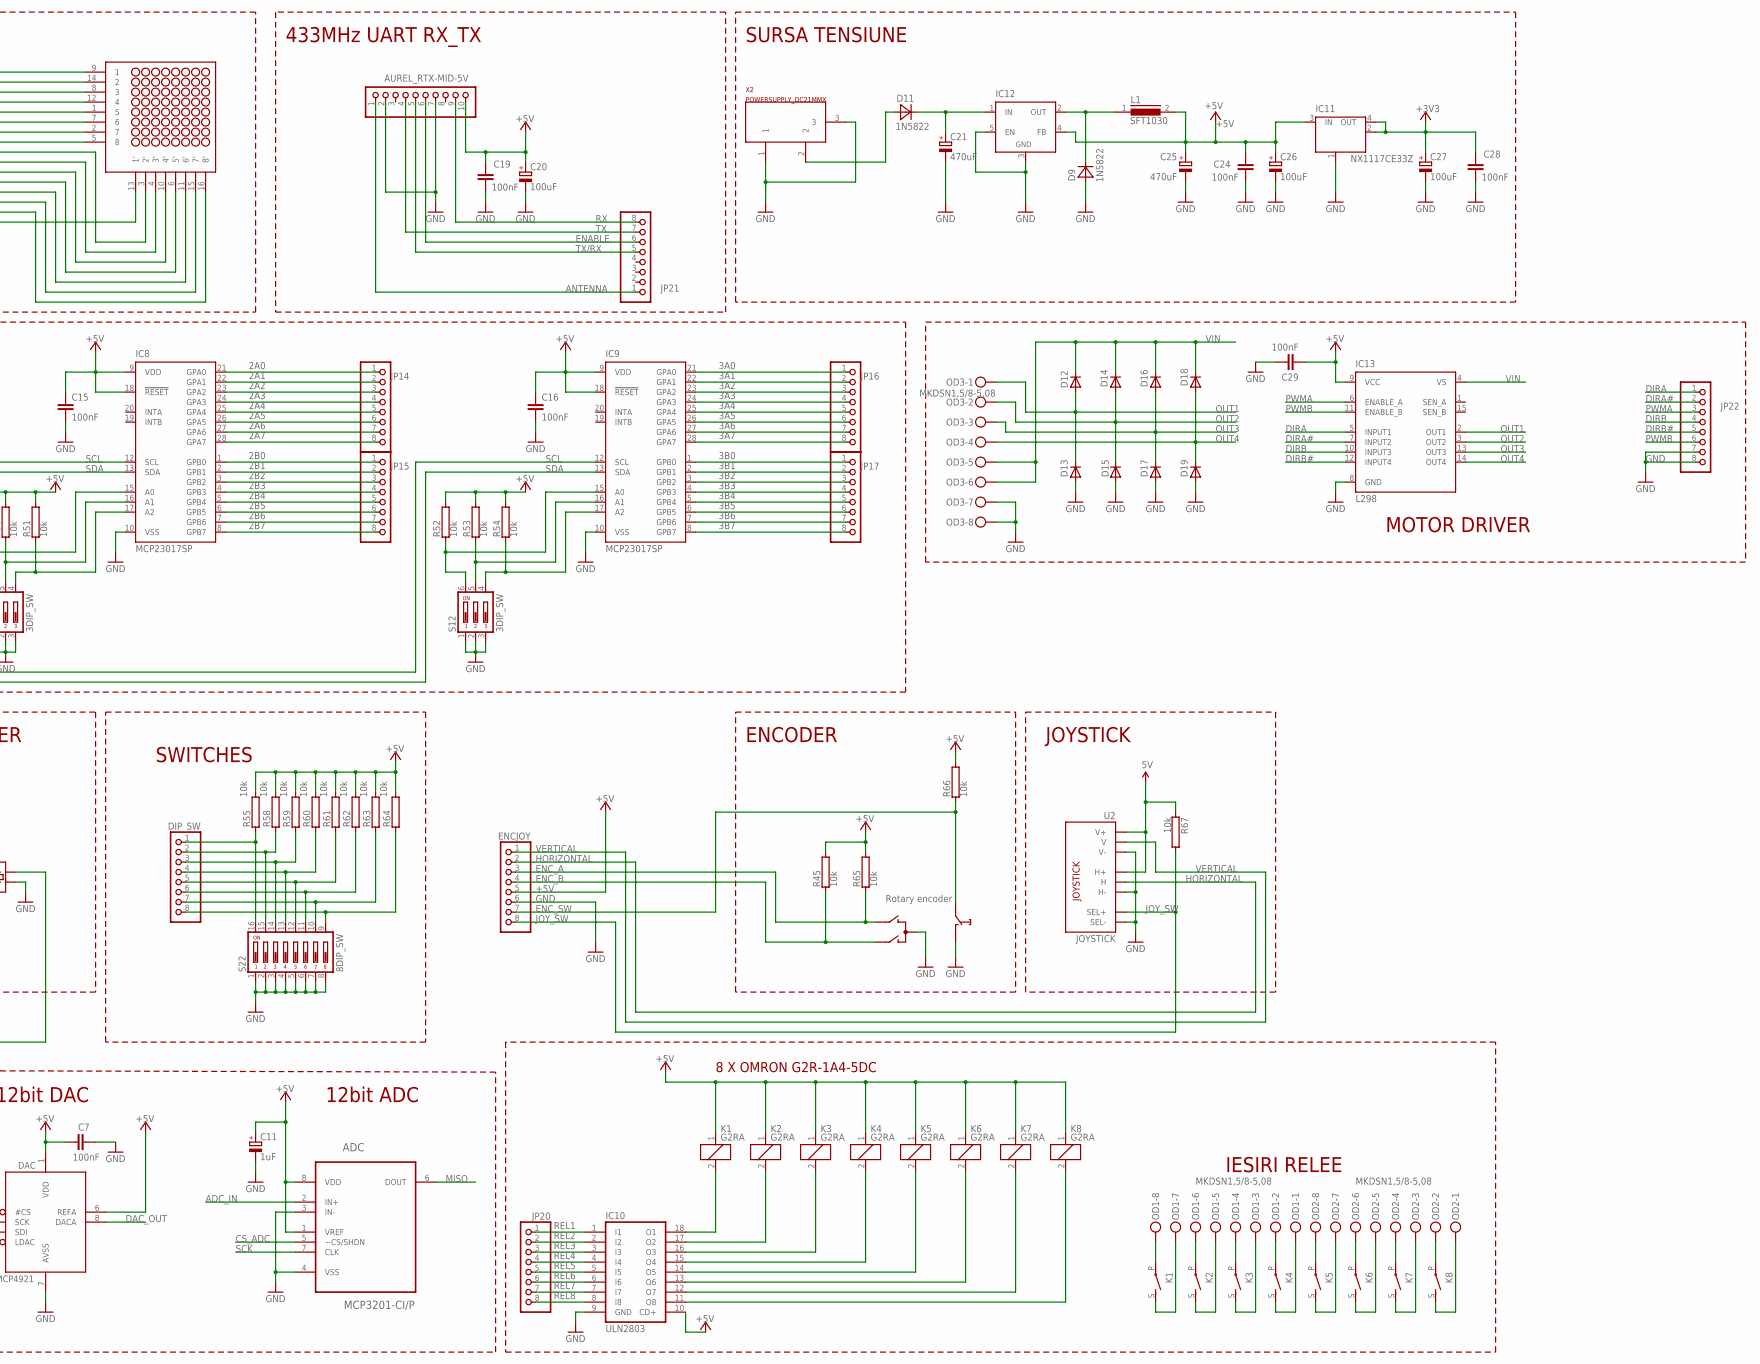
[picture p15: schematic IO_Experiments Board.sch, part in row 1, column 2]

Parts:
7SEG: FH254-108DF08500V; 1X08
ADC: MCP3201-CI/P; DIL08
AUREL_RTX-MID-5V: FH254-110DF08500V; 1X10
B1, B2, B3, B4, B5, B6, B7, B8: 10-XX; B3F-10XX
BUTTONS: FH254-108DF08500V; 1X08
C1, C2, C4, C6, C7, C8, C9, C10, C12, C13, C14, C15, C16, C17, C19, C23, C24, C28, C29: 100nF; C5B2.5
C3, C5: 1uF; E2,5-6
C11: 1uF; E2,5-5
C20, C26, C27: 100uF; E2,5-6
C21, C25: 470uF; E5-10,5
COMMUNICATION: FH254-108DF08500V; 1X08
CONTRAST: 20k; CA6V
D9, D11: 1N5822; DO201-15
D12, D13, D14, D15, D16, D17, D18, D19: MBRA140; DO201-15
DAC: MCP4921; DIL08
DIP_SW: FH254-108DF08500V; 1X08
DIS1: TUXGR_16X2_R2
DISP1: LFD039AUE
ENCJOY: FH254-108DF08500V; 1X08
EXT_SENS: FH254-106DF08500V; 1X06
IC1, IC10: ULN2803; DIL18
IC2: 4511N; DIL16
IC3: PCF8563P; DIL08
IC4, IC8, IC9: MCP23017SP; DIL28-3
IC5: MAX7219CNG; DIL24-3
IC6: 74125N; DIL14
IC7: AT24CP; DIL08
IC11: NX1117CE33Z; SOT223
IC12: LM2596TV; TO220-51
IC13: L298; MULTIWATT-15
IR: M03LONGPADS; 1X03_LONGPADS
JP6, JP7, JP12, JP14, JP15, JP16, JP17, JP20, JP21, JP22: FH254-108DF08500V; 1X08
K1, K2, K3, K4, K5, K6, K7, K8: G2RA
L1: SFT1030
LCDH: FH254-108DF08500V; 1X08
LCDL: FH254-108DF08500V; 1X08
LED1, LED2, LED3, LED4, LED5, LED6, LED7, LED8: GREEN_5mm; LED5MM
LEDS: FH254-108DF08500V; 1X08
OD1, OD2, OD3: MKDSN1,5/8-5,08
POTS: FH254-108DF08500V; 1X08
Q1: 32.768 kHz; QS
R1, R2, R3, R4, R5, R6, R7, R8, R18, R19, R20, R21, R22, R23, R24: 220; RS1/8
R9, R10, R11, R12, R13, R14, R15, R16, R29, R30, R31, R32, R33, R43, R44, R45, R46, R47, R48, R49, R50, R51, R52, R53, R54, R55, R56, R57, R58, R59, R60, R61, R62, R63, R64, R65, R66, R67: 10k; RS1/8
R17: RRS1/8; RS1/8
R25, R26, R27, R28: 4.7k; RS1/8
R34, R35, R36, R37, R38, R39, R40, R41: 20k; CA6V
R42: 27k; RS1/8
S9, S10, S11, S12, S13: 3DIP_SW; DS-03
S22: 8DIP_SW; DS-08
SENSORS: FH254-108DF08500V; 1X08
SG1: 0550_PKM13EPYH4002-B0; BUZZER-12MM-NS-P5MM
SW1: EC12E_SW; ALPS_EC12E_SW
T1, T2, T3, T4: BC547; TO92
TMP1: TMP36; BC-TO92
U2: JOYSTICK
U$5: LMD12088AUE-101A; NFM-12881BG-11
U$8: 25VF512A-33SAE; SOIC-8
X2: POWERSUPPLY_DC21MMX; POWERSUPPLY_DC-21MM

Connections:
1A0: IC4.21 (GPA0), JP6.1
1A1: IC4.22 (GPA1), JP6.2
1A2: IC4.23 (GPA2), JP6.3
1A3: IC4.24 (GPA3), JP6.4
1A4: IC4.25 (GPA4), JP6.5
1A5: IC4.26 (GPA5), JP6.6
1A6: IC4.27 (GPA6), JP6.7
1A7: IC4.28 (GPA7), JP6.8
1B0: IC4.1 (GPB0), JP7.1
1B1: IC4.2 (GPB1), JP7.2
1B2: IC4.3 (GPB2), JP7.3
1B3: IC4.4 (GPB3), JP7.4
1B4: IC4.5 (GPB4), JP7.5
1B5: IC4.6 (GPB5), JP7.6
1B6: IC4.7 (GPB6), JP7.7
1B7: IC4.8 (GPB7), JP7.8
2A0: IC8.21 (GPA0), JP14.1
2A1: IC8.22 (GPA1), JP14.2
2A2: IC8.23 (GPA2), JP14.3
2A3: IC8.24 (GPA3), JP14.4
2A4: IC8.25 (GPA4), JP14.5
2A5: IC8.26 (GPA5), JP14.6
2A6: IC8.27 (GPA6), JP14.7
2A7: IC8.28 (GPA7), JP14.8
2B0: IC8.1 (GPB0), JP15.1
2B1: IC8.2 (GPB1), JP15.2
2B2: IC8.3 (GPB2), JP15.3
2B3: IC8.4 (GPB3), JP15.4
2B4: IC8.5 (GPB4), JP15.5
2B5: IC8.6 (GPB5), JP15.6
2B6: IC8.7 (GPB6), JP15.7
2B7: IC8.8 (GPB7), JP15.8
3A0: IC9.21 (GPA0), JP16.1
3A1: IC9.22 (GPA1), JP16.2
3A2: IC9.23 (GPA2), JP16.3
3A3: IC9.24 (GPA3), JP16.4
3A4: IC9.25 (GPA4), JP16.5
3A5: IC9.26 (GPA5), JP16.6
3A6: IC9.27 (GPA6), JP16.7
3A7: IC9.28 (GPA7), JP16.8
3B0: IC9.1 (GPB0), JP17.1
3B1: IC9.2 (GPB1), JP17.2
3B2: IC9.3 (GPB2), JP17.3
3B3: IC9.4 (GPB3), JP17.4
3B4: IC9.5 (GPB4), JP17.5
3B5: IC9.6 (GPB5), JP17.6
3B6: IC9.7 (GPB6), JP17.7
3B7: IC9.8 (GPB7), JP17.8
+3V3: C9.2, C27.+, C28.1, IC11.2 (OUT), IC11.4 (OUT), R56.2, R57.2, U$8.8 (VDD)
+5V: ADC.1 (VREF), ADC.8 (VDD), AUREL_RTX-MID-5V.10, C1.1, C2.1, C3.+, C4.1, C5.+, C6.1, C7.1, C8.1, C10.1, C11.+, C13.1, C14.1, C15.1, C16.1, C17.1, C19.1, C20.+, C24.1, C25.+, C26.+, C29.1, COMMUNICATION.1, CONTRAST.E, DAC.1 (VDD), DAC.6 (REFA), DIS1.2 (VCC), ENCJOY.5, EXT_SENS.5, IC1.10 (CD+), IC2.3 (LT), IC2.4 (BI), IC2.16 (VDD), IC3.8 (VDD), IC4.9 (VDD), IC4.18 (!RESET), IC5.19 (VCC), IC7.8 (VCC), IC8.9 (VDD), IC8.18 (!RESET), IC9.9 (VDD), IC9.18 (!RESET), IC10.10 (CD+), IC11.3 (IN), IC12.4 (FB), IC13.9 (VCC), IR.3, K1.1, K2.1, K3.1, K4.1, K5.1, K6.1, K7.1, K8.1, L1.2, R1.2, R2.2, R3.2, R4.2, R5.2, R6.2, R7.2, R8.2, R9.2, R10.2, R11.2, R12.2, R13.2, R14.2, R15.2, R16.2, R17.2, R29.2, R30.2, R31.2, R32.2, R33.2, R34.E, R35.E, R36.E, R37.E, R38.E, R39.E, R40.E, R41.E, R42.1, R45.2, R46.2, R47.2, R48.2, R49.2, R50.2, R51.2, R52.2, R53.2, R54.2, R55.2, R58.2, R59.2, R60.2, R61.2, R62.2, R63.2, R64.2, R65.2, R66.2, R67.1, SENSORS.8, TMP1.1 (+VS), U2.H1 (H+), U2.V1 (V+)
A: DISP1.11 (A), R18.2
ADC_IN: ADC.2 (IN+), JP12.5
ANTENNA: AUREL_RTX-MID-5V.1, JP21.1
B: DISP1.7 (B), R19.2
BUZZER: SENSORS.2, SG1.- (2)
C: DISP1.4 (C), R20.2
CONTRAST: CONTRAST.S, DIS1.3 (CONTR)
CS_ADC: ADC.5 (~CS/SHDN), JP12.1
CS_DAC: DAC.2 (#CS), JP12.3
CS_FLASH: IC6.12 (I), JP12.2
D: DISP1.2 (D), R21.2
D1: 7SEG.5, R25.1
D2: 7SEG.6, R26.1
D3: 7SEG.7, R27.1
D4: 7SEG.8, R28.1
DAC_OUT: DAC.8 (DACA), JP12.7
DIRA: IC13.5 (INPUT1), JP22.1
DIRA#: IC13.7 (INPUT2), JP22.2
DIRB: IC13.10 (INPUT3), JP22.4
DIRB#: IC13.12 (INPUT4), JP22.5
E: DISP1.1 (E), R22.2
ENABLE: AUREL_RTX-MID-5V.6, JP21.6
ENC_A: ENCJOY.3, R65.1, SW1.B
ENC_B: ENCJOY.4, R45.1, SW1.A
ENC_SW: ENCJOY.7, R66.1, SW1.E (2)
EXTERN_SIG1: EXT_SENS.3, SENSORS.4
EXTERN_SIG2: EXT_SENS.2, SENSORS.3
F: DISP1.10 (F), R23.2
G: DISP1.5 (G), R24.2
GND: ADC.3 (IN-), ADC.4 (VSS), AUREL_RTX-MID-5V.2, AUREL_RTX-MID-5V.7, B1.3, B1.4 (P1), B2.3, B2.4 (P1), B3.3, B3.4 (P1), B4.3, B4.4 (P1), B5.3, B5.4 (P1), B6.3, B6.4 (P1), B7.3, B7.4 (P1), B8.3, B8.4 (P1), C1.2, C2.2, C3.-, C4.2, C5.-, C6.2, C7.2, C8.2, C9.1, C10.2, C11.-, C12.2, C13.2, C14.2, C15.2, C16.2, C17.2, C19.2, C20.-, C21.-, C23.2, C24.2, C25.-, C26.-, C27.-, C28.2, C29.2, COMMUNICATION.2, CONTRAST.A, D9.A, D13.A, D15.A, D17.A, D19.A, DAC.5 (LDAC), DAC.7 (AVSS), DIS1.1 (GND), ENCJOY.6, EXT_SENS.6, IC1.9 (GND), IC2.5 (LE), IC2.8 (VSS), IC3.4 (VSS), IC4.10 (VSS), IC5.4 (GND), IC5.9 (GND), IC6.1 (OE), IC6.4 (OE), IC6.7 (GND), IC6.10 (OE), IC6.13 (OE), IC7.4 (GND), IC7.7 (WP), IC8.10 (VSS), IC9.10 (VSS), IC10.9 (GND), IC11.1 (GND/ADJ), IC12.3 (GND), IC12.5 (EN), IC13.8 (GND), IR.2, JP12.4, JP12.6, JP12.8, JP22.7, JP22.8, LCDH.4, LCDH.5, OD3.7, OD3.8, R34.A, R35.A, R36.A, R37.A, R38.A, R39.A, R40.A, R41.A, R43.1, R44.1, S9.1, S9.2, S9.3, S10.1, S10.2, S10.3, S11.1, S11.2, S11.3, S12.1, S12.2, S12.3, S13.1, S13.2, S13.3, S22.1, S22.2, S22.3, S22.4, S22.5, S22.6, S22.7, S22.8, SG1.+ (1), SW1.C, SW1.D (1), T1.1 (E), T2.1 (E), T3.1 (E), T4.1 (E), TMP1.3 (GND), U2.B2A (SEL-), U2.H3 (H-), U2.V3 (V-), U$8.4 (VSS), X2.1, X2.3
HORIZONTAL: ENCJOY.2, U2.H2 (H)
IA: 7SEG.1, IC2.7 (IA)
IB: 7SEG.2, IC2.1 (IB)
IC: 7SEG.3, IC2.2 (IC)
ID: 7SEG.4, IC2.6 (ID)
IR: IR.1, SENSORS.7
JOY_SW: ENCJOY.8, R67.2, U2.B1A (SEL+)
LCD_D0: DIS1.7 (D0), LCDL.5
LCD_D1: DIS1.8 (D1), LCDL.4
LCD_D2: DIS1.9 (D2), LCDL.3
LCD_D3: DIS1.10 (D3), LCDL.2
LCD_D4: DIS1.11 (D4), LCDL.1
LCD_D5: DIS1.12 (D5), LCDH.8
LCD_D6: DIS1.13 (D6), LCDH.7
LCD_D7: DIS1.14 (D7), LCDH.6
LCD_E: DIS1.6 (E), LCDL.6
LCD_RS: DIS1.4 (RS), LCDL.8
LCD_RW: DIS1.5 (R/W), LCDL.7
LUMINA: C23.1, R17.1, R44.2, SENSORS.1
MISO: ADC.6 (DOUT), COMMUNICATION.6, IC6.6 (O)
MOSI: COMMUNICATION.5, DAC.4 (SDI), IC5.1 (DIN), IC6.2 (I)
unnamed: IC1.1 (I1), LEDS.1
unnamed: IC1.2 (I2), LEDS.2
unnamed: IC1.3 (I3), LEDS.3
unnamed: IC1.4 (I4), LEDS.4
unnamed: IC1.5 (I5), LEDS.5
unnamed: IC1.6 (I6), LEDS.6
unnamed: IC1.7 (I7), LEDS.7
unnamed: IC1.8 (I8), LEDS.8
unnamed: IC1.18 (O1), LED1.K (C)
unnamed: IC1.17 (O2), LED2.K (C)
unnamed: IC1.16 (O3), LED3.K (C)
unnamed: IC1.15 (O4), LED4.K (C)
unnamed: IC1.14 (O5), LED5.K (C)
unnamed: IC1.13 (O6), LED6.K (C)
unnamed: IC1.12 (O7), LED7.K (C)
unnamed: IC1.11 (O8), LED8.K (C)
unnamed: LED1.A, R1.1
unnamed: LED2.A, R2.1
unnamed: LED3.A, R3.1
unnamed: LED4.A, R4.1
unnamed: LED5.A, R5.1
unnamed: LED6.A, R6.1
unnamed: LED7.A, R7.1
unnamed: LED8.A, R8.1
unnamed: B1.1 (S), B1.2 (S1), BUTTONS.1, R9.1
unnamed: B2.1 (S), B2.2 (S1), BUTTONS.2, R10.1
unnamed: B3.1 (S), B3.2 (S1), BUTTONS.3, R11.1
unnamed: B4.1 (S), B4.2 (S1), BUTTONS.4, R12.1
unnamed: B5.1 (S), B5.2 (S1), BUTTONS.5, R13.1
unnamed: B6.1 (S), B6.2 (S1), BUTTONS.6, R14.1
unnamed: B7.1 (S), B7.2 (S1), BUTTONS.7, R15.1
unnamed: B8.1 (S), B8.2 (S1), BUTTONS.8, R16.1
unnamed: IC2.13 (A), R18.1
unnamed: IC2.12 (B), R19.1
unnamed: IC2.11 (C), R20.1
unnamed: IC2.10 (D), R21.1
unnamed: IC2.9 (E), R22.1
unnamed: IC2.15 (F), R23.1
unnamed: IC2.14 (G), R24.1
unnamed: DISP1.12 (CC1), T1.3 (C)
unnamed: DISP1.9 (CC2), T2.3 (C)
unnamed: DISP1.8 (CC3), T3.3 (C)
unnamed: DISP1.6 (CC4), T4.3 (C)
unnamed: R26.2, T2.2 (B)
unnamed: R27.2, T3.2 (B)
unnamed: R28.2, T4.2 (B)
unnamed: R25.2, T1.2 (B)
unnamed: IC3.1 (OSC_I), Q1.1
unnamed: IC3.2 (OSC_O), Q1.2
unnamed: IC5.2 (DIG0), U$5.9 (1)
unnamed: IC5.11 (DIG1), U$5.14 (2)
unnamed: POTS.1, R34.S
unnamed: POTS.2, R35.S
unnamed: IC4.15 (A0), R31.1, S9.6
unnamed: IC4.16 (A1), R32.1, S9.5
unnamed: IC4.17 (A2), R33.1, S9.4
unnamed: POTS.3, R36.S
unnamed: POTS.4, R37.S
unnamed: POTS.5, R38.S
unnamed: POTS.6, R39.S
unnamed: POTS.7, R40.S
unnamed: POTS.8, R41.S
unnamed: K1.P, OD1.8
unnamed: IC5.6 (DIG2), U$5.8 (3)
unnamed: IC5.7 (DIG3), U$5.12 (4)
unnamed: IC5.3 (DIG4), U$5.1 (5)
unnamed: IC5.10 (DIG5), U$5.7 (6)
unnamed: IC5.5 (DIG6), U$5.2 (7)
unnamed: IC5.8 (DIG7), U$5.5 (8)
unnamed: IC5.22 (SEGDP), U$5.13 (1')
unnamed: IC5.17 (SEGG), U$5.16 (8')
unnamed: IC5.14 (SEGA), U$5.3 (2')
unnamed: IC5.16 (SEGB), U$5.4 (3')
unnamed: IC5.20 (SEGC), U$5.10 (4')
unnamed: IC5.23 (SEGD), U$5.6 (5')
unnamed: IC5.21 (SEGE), U$5.11 (6')
unnamed: IC5.15 (SEGF), U$5.15 (7')
unnamed: IC5.18 (ISET), R42.2
unnamed: IC7.1 (A0), R48.1, S10.4
unnamed: IC7.2 (A1), R47.1, S10.5
unnamed: IC7.3 (A2), R46.1, S10.6
unnamed: IC8.15 (A0), R49.1, S11.6
unnamed: IC8.16 (A1), R50.1, S11.5
unnamed: IC8.17 (A2), R51.1, S11.4
unnamed: IC9.15 (A0), R52.1, S12.6
unnamed: IC9.16 (A1), R53.1, S12.5
unnamed: IC9.17 (A2), R54.1, S12.4
unnamed: K1.S, OD1.7
unnamed: K2.P, OD1.6
unnamed: K2.S, OD1.5
unnamed: K3.P, OD1.4
unnamed: K3.S, OD1.3
unnamed: K4.P, OD1.2
unnamed: K4.S, OD1.1
unnamed: K5.P, OD2.8
unnamed: IC10.18 (O1), K1.2
unnamed: IC10.17 (O2), K2.2
unnamed: IC10.16 (O3), K3.2
unnamed: IC10.15 (O4), K4.2
unnamed: IC10.14 (O5), K5.2
unnamed: IC10.13 (O6), K6.2
unnamed: IC10.12 (O7), K7.2
unnamed: IC10.11 (O8), K8.2
unnamed: K5.S, OD2.7
unnamed: K6.P, OD2.6
unnamed: K6.S, OD2.5
unnamed: K7.P, OD2.4
unnamed: K7.S, OD2.3
unnamed: K8.P, OD2.2
unnamed: K8.S, OD2.1
unnamed: IC6.5 (I), U$8.2 (MISO)
unnamed: IC6.3 (O), U$8.5 (MOSI)
unnamed: IC6.8 (O), U$8.6 (SCK)
unnamed: C21.+, D11.C, IC12.1 (IN)
unnamed: IC6.11 (O), U$8.1 (CE)
unnamed: R56.1, S13.5, U$8.3 (WP)
unnamed: R57.1, S13.4, U$8.7 (HOLD)
unnamed: D9.C, IC12.2 (OUT), L1.1
unnamed: D11.A, X2.2
unnamed: DIP_SW.1, R55.1, S22.16
unnamed: DIP_SW.2, R58.1, S22.15
unnamed: DIP_SW.3, R59.1, S22.14
unnamed: DIP_SW.4, R60.1, S22.13
unnamed: DIP_SW.5, R61.1, S22.12
unnamed: DIP_SW.6, R62.1, S22.11
unnamed: DIP_SW.7, R63.1, S22.10
unnamed: DIP_SW.8, R64.1, S22.9
OUT1: D12.A, D13.C, IC13.2 (OUT1), OD3.1
OUT2: D14.A, D15.C, IC13.3 (OUT2), OD3.2
OUT3: D16.A, D17.C, IC13.13 (OUT3), OD3.3
OUT4: D18.A, D19.C, IC13.14 (OUT4), OD3.4
PWMA: IC13.6 (ENABLE_A), JP22.3
PWMB: IC13.11 (ENABLE_B), JP22.6
REL1: IC10.1 (I1), JP20.1
REL2: IC10.2 (I2), JP20.2
REL3: IC10.3 (I3), JP20.3
REL4: IC10.4 (I4), JP20.4
REL5: IC10.5 (I5), JP20.5
REL6: IC10.6 (I6), JP20.6
REL7: IC10.7 (I7), JP20.7
REL8: IC10.8 (I8), JP20.8
RX: AUREL_RTX-MID-5V.9, JP21.8
SCK: ADC.7 (CLK), COMMUNICATION.7, DAC.3 (SCK), IC5.13 (CLK), IC6.9 (I)
SCL: COMMUNICATION.3, IC3.6 (SCL), IC4.12 (SCL), IC7.6 (SCL), IC8.12 (SCL), IC9.12 (SCL), R29.1
SDA: COMMUNICATION.4, IC3.5 (SDA), IC4.13 (SDA), IC7.5 (SDA), IC8.13 (SDA), IC9.13 (SDA), R30.1
SENS_EXTERN: EXT_SENS.4, SENSORS.5
SS: COMMUNICATION.8, IC5.12 (LOAD), R43.2
TEMPERATURA: C12.1, SENSORS.6, TMP1.2 (VOUT)
TX: AUREL_RTX-MID-5V.4, JP21.7
TX/RX: AUREL_RTX-MID-5V.5, JP21.5
VCC: IC6.14 (VCC)
VERTICAL: ENCJOY.1, U2.V2 (V)
VIN: D12.C, D14.C, D16.C, D18.C, IC13.4 (VS), OD3.5, OD3.6

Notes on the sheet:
RTC
LCD
LEDs
BUTTONS
7Seg
IO Expander I2C
POTs
LED_MATRIX
PHOTORESISTOR
SENSOR
LUMINA
EXTERN
TEMPERATURA
12bit DAC
I2C EEPROM
SPI FLASH
12bit ADC
JOYSTICK
BUZZER
8 X OMRON G2R-1A4-5DC
IESIRI RELEE
433MHz UART RX_TX
SURSA TENSIUNE
MOTOR DRIVER
SWITCHES
Rotary encoder
ENCODER

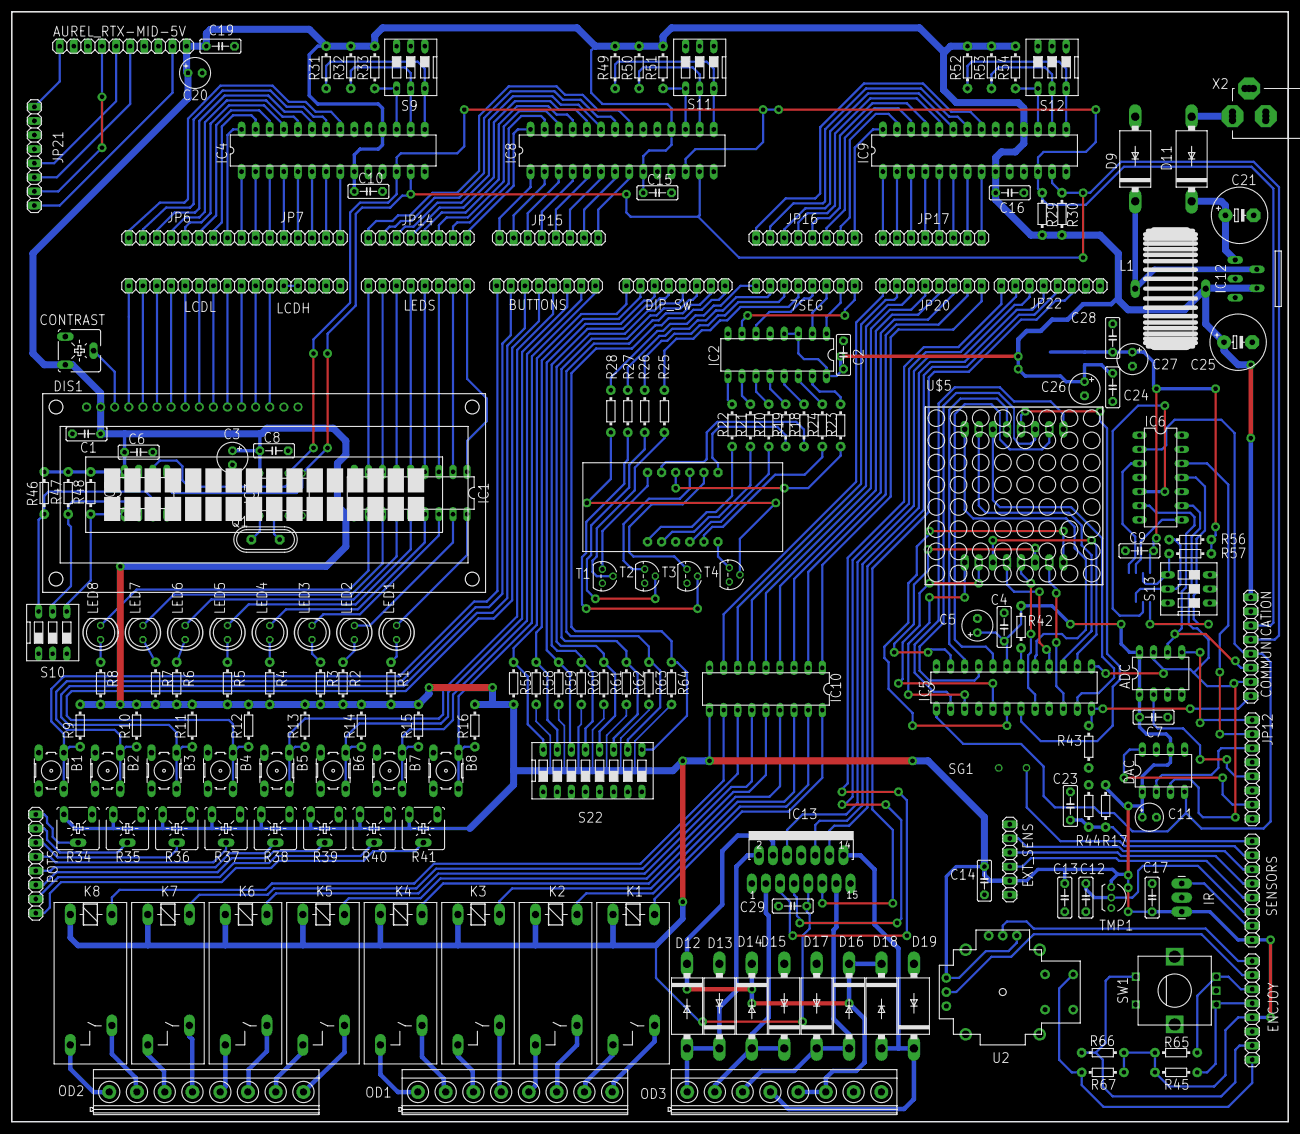
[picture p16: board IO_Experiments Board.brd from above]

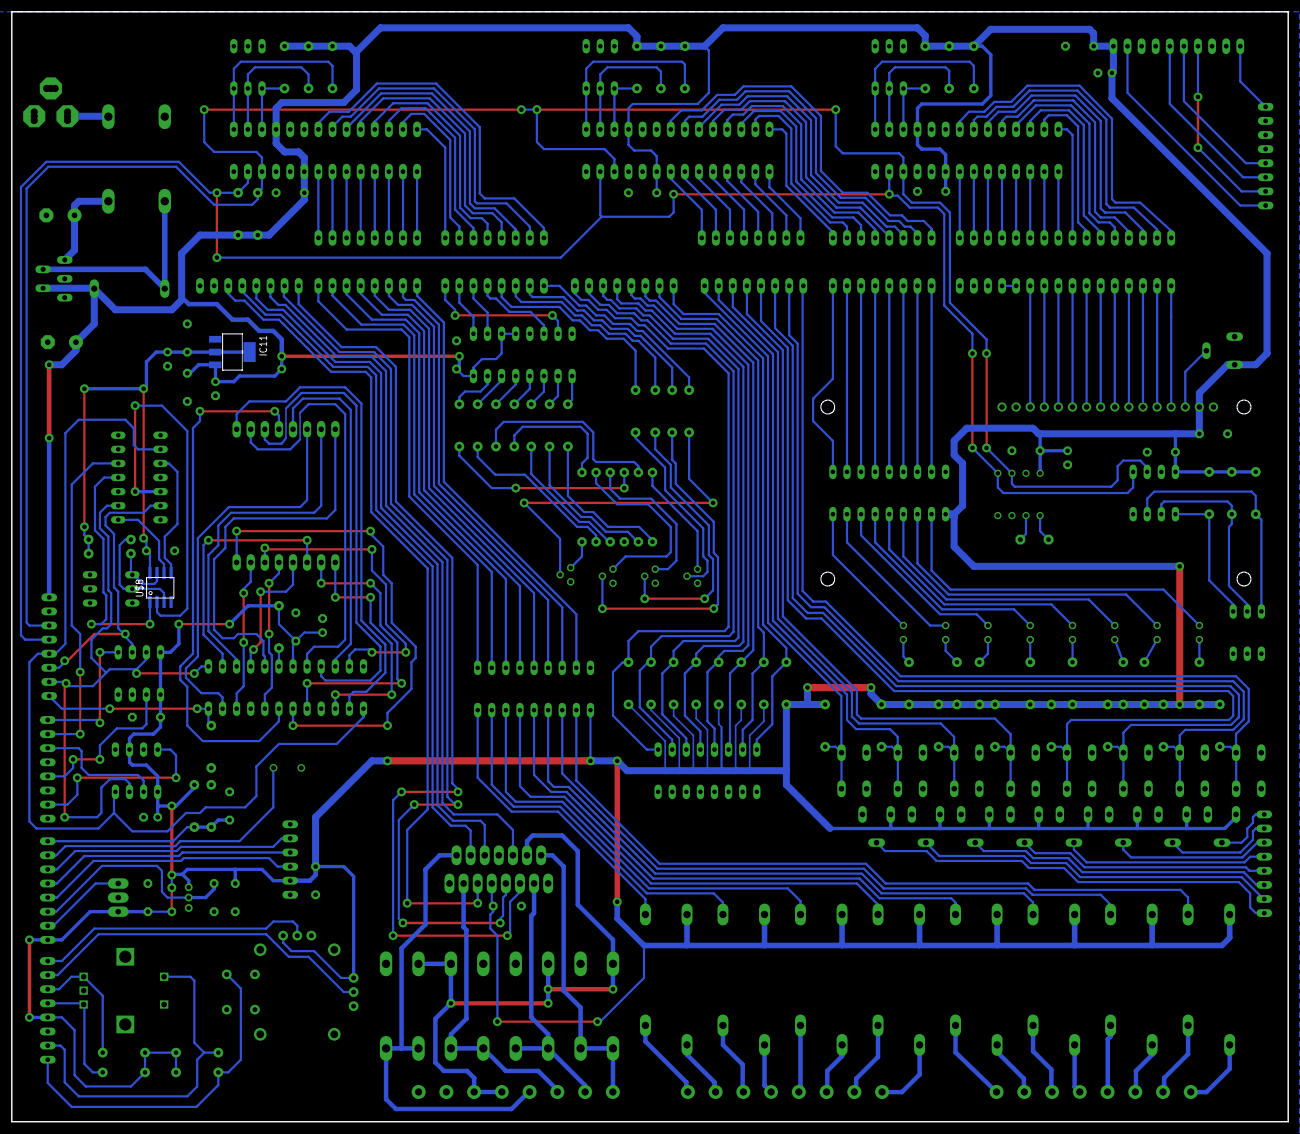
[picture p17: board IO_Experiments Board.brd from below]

Board: 2 copper layers, 230.0 x 200.0 mm, 191 parts (2 on the bottom side), 253 nets.

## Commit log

2018-09-09 pushed all the working files
    [BDO.gbr, IO_Experiment_Board_BOARD DIMENSION.gbr, IO_Experiment_Board_BOTTOM_COPPER.gbr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]
2019-10-19 added signal names on connectors on the board , layer 51
    [IO_Experiments Board.brd, IO_Experiments Board.sch]

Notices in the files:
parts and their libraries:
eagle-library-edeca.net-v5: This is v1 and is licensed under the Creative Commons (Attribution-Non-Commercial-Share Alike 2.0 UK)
